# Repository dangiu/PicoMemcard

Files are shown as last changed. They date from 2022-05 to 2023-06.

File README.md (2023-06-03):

# PicoMemcard



PicoMemcard allows you to build your own supercharged PSX Memory Card that can be connected to your computer via USB in order to transfer saves directly to/from your PSX. You can use it to repurpose broken/counterfeit Memory Cards creating a better one using only a Raspberry Pi Pico.

## Features
* Able to faithfully simulate PSX Memory Card
* USB connection to import/export saves
* Allows to copy saves to/from any other memory card (using original PSX file manager)
* Allows to play burned CDs (thanks to [FreePSXBoot])
* Cheaper than an original memory card
* Can store hudreds of memory card images

## Bill of materials
* **Raspberry Pi Pico** (around $5)
* One of:
    * Custom [PicoMemcard PCB](#picomemcard-pcb)
    * Broken/Counterfeit/Original PSX Memory Card (counterfeit ones can be found on AliExpress for around $2-3)
    * PSX/PS2 Controller Cable
    * CAT5 network cable and a bit of creativity.

Basically anything that will allow you to interface with the memory card slot pins will do. If you have a broken contoller you can cut off the cable and use that since controllers and memory cards share the same bus. Of course, plugging your memory card into the controller slot will prevent you from using 2 controllers at the same time.

[This guy] assembled one using a 3d-printed plastic shell and simple CAT5 network cable. I belive this is the cheapest method anybody has come up with until now.

In total building a PicoMemcard wil cost you less than buying a used original Memory Card!

## Video
PicoMemcard (https://youtu.be/sPZsESXcDcc)

## PicoMemcard PCB

These are the custom PCBs designed and manufactured specifically for this application. They are not strictly required but make it much easier to build PicoMemcard since you don't need to cut up another memory card and all the soldering pads are easily accessible. All you need to do is to solder the Pico/RP2040-Zero on top of the PCB using a soldering iron.

The Raspberry Pi Pico or RP2040-Zero must sit flush on top of the PCB, fortunately both the Pico and RP2040-Zero provide castellated holes that are easy to solder directly to the PCB's pads. You can use some electrical tape to hold the board in place while you solder the first pins.

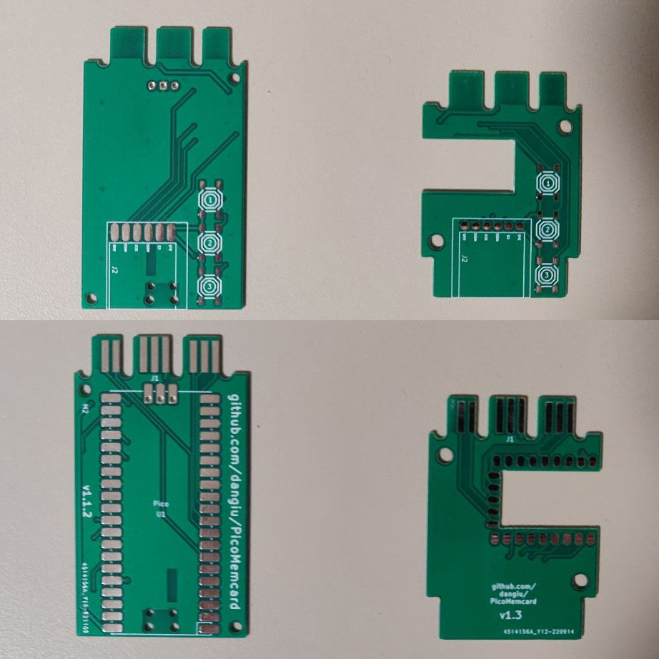
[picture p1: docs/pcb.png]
Custom PCBs


I've created a new version of the original PCBs the major difference are:
* The general size is smaller
* A new micro SD card module is supported. This module is smaller, easier to solder and should solve some of the power related issues that were previously present
* Is fitted for the installation of phisical switches used to switch memory card when PicoMemcard+ is used in systems that do not support switching via controller input (e.g. all PS2 models).

The KiCad and Gerber files are available in the repository. If you want to support the project you can request a PCB [from here]. 
Keep in mind that with the PS2 support release that will eventually happen the PCB may undergo some additional changes before its design is finalized.

## PicoMemcard using Memory Card
Raspberry Pi Pico and RP2040-Zero require different pin usage for full compatibility.

The wiring diagrams below show how to build PicoMemcard by wiring respectively a Pico and an RP2040-Zero to a counterfeit memory card. For the other cases (wiring directly to the PSX or using a controller cable) the pins on Pico and RP2040-Zero are the same, the pinout of the PSX/controller can be found on [psx-spx]. The images show the bottom side of the memory card with the cover removed.

Pico Wiring Diagram

RP2040-Zero Wiring Diagram

The dashed line on the PCB of the memory card is where you should cut a groove deep enough to disconnect the original circuitry from the traces. The yellow squares above the line indicate where you should scrape away the protective film in order to expose the copper traces and solder the wires onto them.

Finally the area at the bottom of the memory card is where you can cut a hole to feed the wires through connecting them to the Pico.
If you are using an RP2040-Zero you can also cut away part of the original Memory Card circuitry to fit it inside the original shell.

The connections in the PicoMemcard+ area are optional and only required if you want to build **PicoMemcard+** (using the optional MicroSD expansion board). Also remember to connect both ground and power to your SD card module (see [MicroSD Module](#microsd-module-for-picomemcard) section for more information).

## PicoMemcard vs PicoMemcard+
Since some features cannot be implmented when using only a Pico/RP2040-Zero but require additional hardware, I've decided to split the project in two versions:
* **PicoMemcard** simplest device to build, only requires a Raspberry Pi Pico / RP2040-Zero
* **PicoMemcard+** more complex and powerful device. Supports additional features such as multiple memory card images but requires additional hardware (namely the MicroSD SPI expansion board).

This approach was choosen because many people want a solution that is as cheap as possible and don't care about additional features. Conversely, others would like to have additional features even if it means spending a bit more money.

The current release of PicoMemcard+ additionally to all the features of PicoMemcard supports:
* Trasparent write-back: the sync operation performed to save new data no longer reults in the memory card appearing as if was briefly disconnected.
* Multiple memory card image switchable through controller input.

## MicroSD Module for PicoMemcard+
There are many variations of MicroSD expansion boards with different pinouts and interfaces. The only requirement for PicoMemcard+ is that the module must provide an SPI interface. SPI interfaces have at least the following pins:
* Chip Select (CS) (sometime also called Slave Select (SS)).
* Clock (SCK or CLK).
* Master Output Slave Input (MISO).
* Master Input Slave Output (MOSI).

In addition you will need to connect power and ground to your module, some modules are design to work with 5V others with 3.3V (or both), luckily for us both voltages are available on Pico and RP2040-Zero as shown in the schematic in the section [above](#picomemcard-using-memory-card). Some module provides additional pins that can be left disconnected.

The new versions of the PCB are designed to use small modules such as this one:

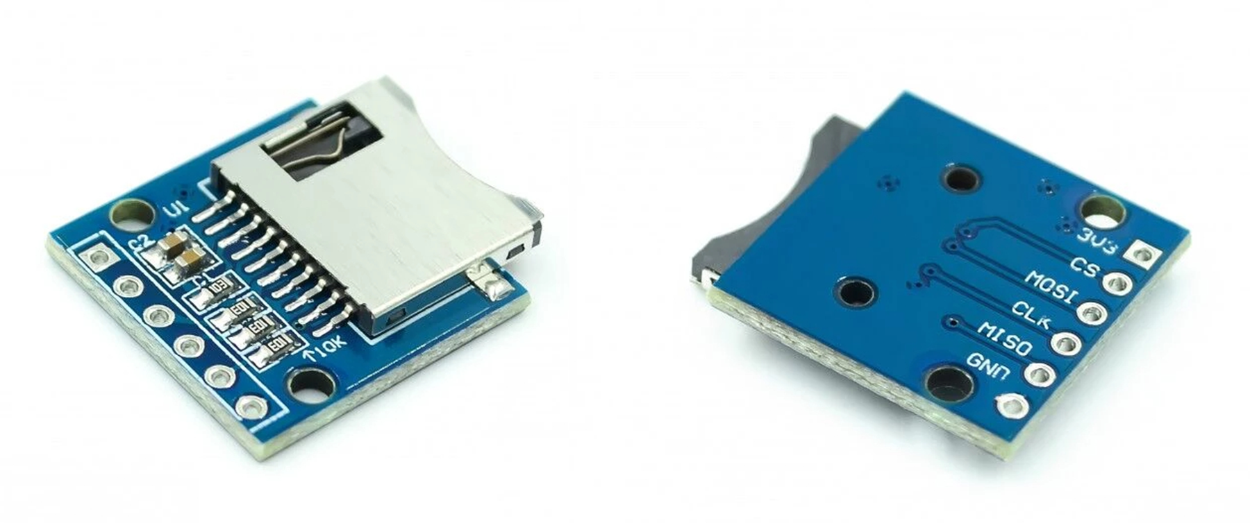
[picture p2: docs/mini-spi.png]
Smaller MicroSD SPI expansion board


This is mainly due to the following reasons:
* It comes withouth pre-soldered headers which makes it easier to solder onto the PicoMemcard PCB.
* Its smaller form factor allows for more flexibility.
* It should have less power issue than prevously used modules.

A good source for these modules is Aliexpress, in general you can search for `MicroSD SPI Expansion Board` and buy the cheapest one you find.

## Installation
1. Download the latest [release] for your board (Raspberry Pi Pico and RP2040-Zero require different binaries).
2. While pressing the 'BOOTSEL' or 'BOOT' button on your board, plug it into your computer. 
3. Drag and drop the PicoMemcard release onto your Raspberry Pi Pico.
4. PicoMemcard should appear on your PC as a USB drive.
5. Upload a memory card image to your PicoMemcard.

## Transfering Data
Memory card images must be exactly 128KB (131072 bytes) in size. PicoMemcard and PicoMemcard+ only support files with `.MCR` extensions. However, `.MCR` and `.MCD` extensions are interchangable and can be converted to one another simply via renaming.
For other file formats, try using [MemcardRex] for converting to the desired output.

* **PicoMemcard** only supports a single image which must be named exactly `MEMCARD.MCR`.
* **PicoMemcard+** supports hundreds of images. Each image must be named `N.MCR` where `N` is an integer number (e.g. `0.MCR`, `1.MCR`...). On boot your previously loaded image will be reloaded, unless it's a fresh card then `0.MCR` will be loaded.

Inside `docs/images` you can find two memory card images. One has a couple of saves on it so you can test if everything works correctly, the other is completely empty.

## Switching/Creating Images
On **PicoMemcard+** you can switch the active memory card image with the following inputs:
* `START + SELECT + DPAD UP` will switch to the next image (e.g from `1.MCR` to `2.MCR`).
* `START + SELECT + DPAD DOWN` will switch to the previous image (e.g from `1.MCR` to `0.MCR`).

Additionally you can create a new empty memory card image (and automatically switch to it) by pressing  `START + SELECT + TRIANGLE`.

**Attention**: this method only works on PSX if the controller used to provide the input is plugged in the same slot as PicoMemcard (exactly under it). Using a controller from a different slot will have no effect.

Additionally this method does not work on PS2 Memory Cards and Controllers are wired on a different bus.

## Syncing Changes
Generally speaking, new data written to PicoMemcard (e.g. when you save) is permanently stored only after a short period of time (due to hardware limitation). The on board LED indicates whether all changes have been stored or not, in particular:
* On Rapsbery Pi Pico the LED will be on when all changes have been saved, off otherwise.
* On RP2040-Zero the LED will be solid green when all changes have been saved, red otherwise.

Unlike **PicoMemcard+** that tries to write new changes as soon as possible, **PicoMemcard** will generally do it only after a period of inactivity (around 5 seconds). If you want to force **PicoMemcard** to immediately sync you can press `START + SELECT + TRIANGLE`.

**Attention**: after you save your game, make sure to wait for the LED to be solid green before turning off the console otherwise you might lose your more recent progress!

## 3D-Printed Case
I've finally designed a 3D-printable case for the different PicoMemcard PCBs. It helps inserting correctly the PCB and ensuring that the the connection to the PSX is optimal. The same result, albeit more janky, can be achieved using a folded sheet of paper as a spacer.

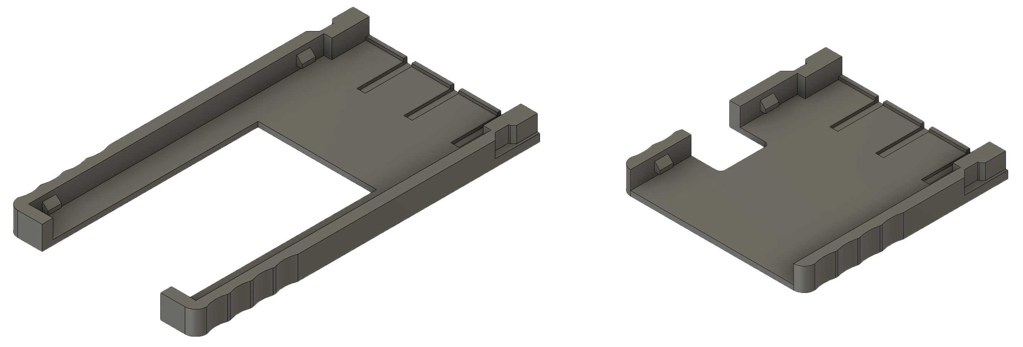
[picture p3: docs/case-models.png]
Model of 3D-printed case


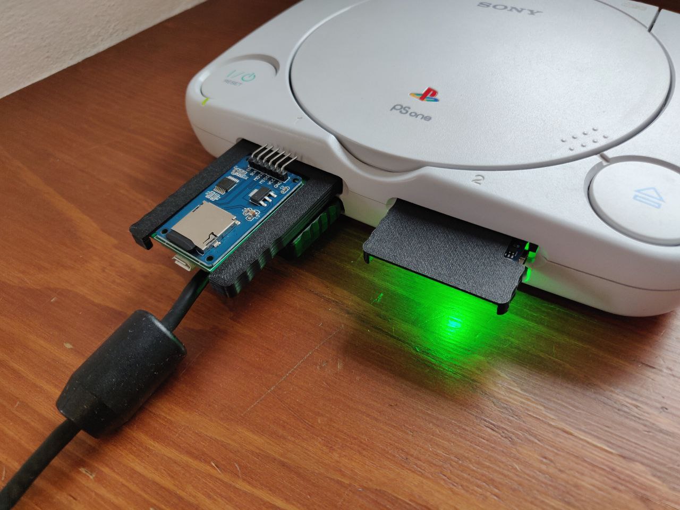
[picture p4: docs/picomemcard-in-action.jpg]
PicoMemcard in Action!


The cases are designed following a minimalistic approach, they consist of a single piece which holds tightly the PCB using very small clips without requiring any additional hardware. To assemble it, simply slide in the PCB from the back of the case (opposite to the side connecting to the PSX). Cases for the fullsize PCB are designed to support the MicroSD expansion module.

Here is the download for the STL files:
* [Design by DanGiu](https://www.thingiverse.com/thing:5488778)

If you don't like this case you can check out other designs many people have already created! I've not tested them personally but here they are:
* [Design by brik1111](https://www.thingiverse.com/thing:5453156)
* [Design by bbsan2k](https://www.thingiverse.com/thing:5460187)

## Troubleshooting and LED Indicator
Generally speaking the onboard LED will provide a pretty good indication regarding the status of PicoMemcard.

In particular, the RP2040-Zero has RGB LED that provides a more clear output. The Pico on the other hand as only a green LED and different blinking patterns indicate different statuses.

### PicoMemcard Status
| Status | Pico | RP2040-Zero
| --- | --- | --- |
| Failed to read memory card image | Slow blinking led  | Red blinking led
| Data not fully synced (do not turn off PSX)| Led off | Red led (or flashing red and green) |
| Data synced | Led on | Green solid led |

### PicoMemcard+ Status
| Status | Pico | RP2040-Zero
| --- | --- | --- |
| Failed to read SD card | Blinking led  | Red blinking led
| Data not fully synced (do not turn off PSX)| Led off | Red led (or flashing red and green) |
| Data synced | Led on | Green solid led |
| Memory Card image changed | Three fast blinks | Single blue blink |
| Memory Card image not changed (end of list) | Nine fast blinks | Single orange blink |
| New Memory Card image created | Multiple very fast blinks | Single light blue blink |

## General Warnings
I would recommend to never plug PicoMemcard both into the PC (via USB) and the PSX at the same time! Otherwise the 5V provided by USB would end up on the 3.3V rail of the PSX. I'm not really sure if this could cause actual damage but I would avoid risking it.

If you really need to have the Pico plugged into both the USB and PSX (e.g. for debugging purposes), disconnect the 3.3V line from the VBUS pin. In this way you can power on the Pico using a simple USB phone charger or by plugging it into your PC.

As a disclamer, I don't take any responsability for what will happen to your console when using PicoMemcard/PicoMemcard+.

## Project Updates
### 5 February 2023
Sorry everybody but I've been quite inactive on the project lately. Due to a change of job IRL I have less time to work for the moment.
Anyway, behind the scenes I've been trying to add support for PS2 memory card but I'm afraid that will require the addition of an extra hardware component unless I am able to develop an efficient cacheing mechanisms or something similar. Anyway I'll keep working on it when I have free time. I have in mind many improvement for the project and I think the future of it is going to be exciting.

Special thanks to everybody that supported it so far! You are all amazing.

## Design
For people interested in understanding how PicoMemcard works I provide a more extensive explanation in [this post] (although now somewhat outdated).

## Thanks To
* [psx-spx] and Martin "NO$PSX" Korth - PlayStation Specifications and documented Memory Card protocol and filesystem.
* [Andrew J. McCubbin] - Additional information about Memory Card and Controller communication with PSX.
* [littlefs] - Filesystem designed to work on NOR flash used by many microcontrollers, including the Raspberry Pi Pico.
* [ChaN FatFS] - FAT filesystem implementation for embedded devices.
* [Scoppy] - Use your Raspberry Pi Pico as an oscilloscope, very cheap and accurate. Without this I would have not been able to debug many issues.
* [PulseView] - Used to import, visualize and manipulate the data from Scoppy on a PC.

[FreePSXBoot]: https://github.com/brad-lin/FreePSXBoot
[psx-spx]: https://psx-spx.consoledev.net/pinouts/#controller-ports-and-memory-card-ports
[Andrew J. McCubbin]: http://www.emudocs.org/PlayStation/psxcont/
[littlefs]: https://github.com/littlefs-project/littlefs
[ChaN FatFS]: http://elm-chan.org/fsw/ff/00index_e.html
[Scoppy]: https://github.com/fhdm-dev/scoppy
[PulseView]: https://sigrok.org/wiki/PulseView
[release]: https://github.com/dangiu/PicoMemcard/releases/latest
[this post]: https://dangiu.github.io/2022/05/13/picomemcard.html
[from here]: https://forms.gle/f6XHtz6W5fn5qDZV7
[This guy]: https://github.com/MrSVCD/PicoPSX_3D
[MemcardRex]: https://github.com/ShendoXT/memcardrex

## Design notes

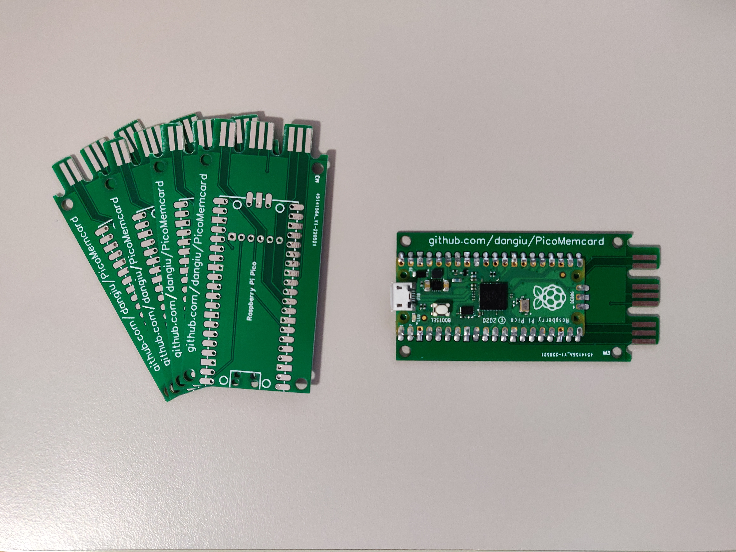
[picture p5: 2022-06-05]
docs/PCBs.jpg

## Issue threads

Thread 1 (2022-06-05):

VBUS connected to 3.3v

darrena092, 2022-06-05:
Hey,

Just setting this up, and I've noticed you say to connect VBUS on the pico to 3.3v on the PS2, which creates the danger that when plugging in the pico to usb, you'd be connecting that to 5v.

You can just connect the 3.3v memory card pin to 3.3v on the pico, and it'll power it just fine. That'll also allow you to safely have the board plugged into the PC for debugging at the same time.

darrena092, 2022-06-05:
(Also just to note I'm testing this with a Playstation 2 - I guess in theory at least it should recognise the PS1 memory card)

dangiu, 2022-06-05:
The problem with this approach is that the Pico can be powered on VSYS using only 3.3V (it expects a voltage already regulated). Some playstation models are documented to output more than 3.3 volts on that line (up to 5 or 7 if i remember correctly) so connecting it to VSYS would risk damaging the Pico.

darrena092, 2022-06-05:
Ah fair enough, mine didn't blow up anyways 🤣 - I'll measure the 3.3v line on the ps1 tomorrow.

dangiu, 2022-06-05:
Okk go for it! Same goes for my PSOne Model SCPH-102, measured some time ago but I guess you can never be too sure 😄

darrena092, 2022-06-08:
3.45v, a little on the high side. Will probably just leave the 3v3 line disconnected and power it from the PC while I'm working on it. I don't think an extra 150mv is going to cause all that big of a problem, but might be a good idea if there's a v2 PCB to include some voltage regulation, even just an SMT LM317.

dangiu, 2022-06-09:
Fortunately the Pico already regulates the power provided on VBUS (since USB normally uses 5 volts) down to 3.3V so there's no need for additional components 😀

Closed 2022-06-09.

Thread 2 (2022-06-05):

Not detected by Playstation 2 - SCPH-39003

darrena092, 2022-06-05:
Hi,

Tested this today with my original fat playstation 1, worked perfectly (using the breakout board I talked about on the Reddit thread that I'd made a while back).

When trying it with my Playstation 2 (SCPH-39003), it wasn't detected at all. Not sure what the issue there is, but I'll try to debug it if I get time. I understand the primary purpose of this project is for use on the Playstation 1, but it'd be nice if it also worked in backwards compatibility mode on the PS2 also.

dangiu, 2022-06-05:
Ok! Glad to hear it works on FAT PS1, could you provide the exact model? I'm just curious to know. I'm not sure on the protocol the PS2 uses to communicate with memory card, maybe the interaction is slightly different and messes up the PIO state machines.
If you have an oscilloscope it would simplify the debugging process a ton! I used another Raspberry Pi Pico together with [Scoppy](https://github.com/fhdm-dev/scoppy). Thanks for your contribution!

darrena092, 2022-06-05:
The PS1 is a SCPH-9002 btw

darrena092, 2022-06-08:
This might be simpler than what you think.

Getting the following over UART:
```
SYNC    OK

Unknown MC CMD: 11

Unknown MC CMD: f3
WRITE  003f
```

Looks like there are just a few unimplemented commands that the PS2 sends, which the PS1 does not. I'll work on figuring out what they are and get them handled.

darrena092, 2022-06-08:
Nah scratch that, something weird going on. Going to hook up the logic analyser.

darrena092, 2022-06-08:
I have a theory, those 0x11 and 0xF3 commands aren't actually real. They seem to be generated when the PS2 does this:

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

I unfortunately don't have a real ps1 memory card to test with at the minute, but I'd imagine this must be part of some sort of mechanism to figure out whether or not the memory card is a PS2 or PS1 one.

The issue might be ACKing that. Hard to say without having a real one to test with at the minute, but I'd say we probably only want to ACK on /SEL with 8 clock pulses. I'll see if I can modify it to do that and report back.

uyjulian, 2022-07-08:
For reference, if the card inserted was no card or PS2 card before, it will attempt to probe in this order: PS2, PS1, PocketStation

Otherwise, it will probe in this order: PS1, PS2, PocketStation

Reference: https://github.com/ps2dev/ps2sdk/blob/f5401e0c95e85900464c550060da4c9b9ee6b67b/iop/memorycard/mcman/src/main.c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

darrena092, 2022-07-10:
Fixed in #10 (not yet merged) - though the fix is specific to the SD card version of the project due to problems with littlefs hard faulting the CPU with the new sector at a time sync process.

dangiu, 2022-08-02:
Fixed in new release

Closed 2022-08-02.

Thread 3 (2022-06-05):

With RP2040 zero，ps1 not detect

sceic, 2022-06-05:
With RP2040 zero, the .mcr file can be recognized through usb after writing the program. However, it cannot be detected by ps1 9002. It has been checked  3.3v power supply and the data line connection are not abnormal.

sceic, 2022-06-05:
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

darrena092, 2022-06-05:
How are you testing whether or not it detects it? Did you program it with an image containing saves and they don't show up in the bios?

Also, have you checked continuity between the edge connector on the memory card and the copper pads on the rp2040 zero board?

sceic, 2022-06-06:
How are you testing whether or not it detects it? Did you program it with an image containing saves and they don't show up in the bios?

A: Tested through the ps1 bios - memory card management interface, the slot 2 card cannot be copied to the Pico memorycard（slot 1）.

Also, have you checked continuity between the edge connector on the memory card and the copper pads on the rp2040 zero board?

Edit: Did you also cut the traces fully? It's hard to see from the photo. That could cause it to have a bad time too.

darrena092, 2022-06-06:
That's really interesting, so it works in a game, but not in the bios. You can't see your save icons in the memory card browser? In your first comment you said it's a SCPH-9002?

dangiu, 2022-06-06:
Very interesting indeed. SCPH-9002 is a PAL model running bios version 4.1 I believe. It would be interesting to test if other models with the same firmware version behave equally.
I have a couple of questions:
1. Do you have an oscilloscope? Could you capture the data being exchanged between PicoMemcard and PSX
2. In what game can you use it correcly to save/load? Could you try a couple different games?

sceic, 2022-06-07:
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

I have an oscilloscope Rigol DS1102Z-E (100MHz bandwidth and 1GSa/s) but need guidance on how to test data exchange as I just bought it.

The game is FinalFantasy 8, other games have not been tested, I will try other games later, such as Tomb Raider 2.

sceic, 2022-06-07:
> That's really interesting, so it works in a game, but not in the bios. You can't see your save icons in the memory card browser? In your first comment you said it's a SCPH-9002?

In bio.  memory card browser no icons.  and can't copy saves betwin slot1&2.

Yes,my PS1 is SCPH-9002.

darrena092, 2022-06-07:
Odd, I'm using the same console, SCPH-9002 and saves show up fine in the bios.

dangiu, 2022-06-07:
>

I'm not familiar with that model of oscilloscope but I can give you some general advices:
- double all of the connection on the memory card side and hook them up to the oscilloscope
- look for something like "record fixed amount of samples"
- plug in your PicoMemcard and trigger the recording process measuring the communication
- desolder the RP2040 zero leads but leave the connection to the oscilloscope
- now plug in a working memory card and trigger again the sampling process
If you could share both results (RP2040 zero communication and working memory card communication) it would be really helpful to debug your issue.

dangiu, 2022-06-07:
Ok keep me updated 👍

sceic, 2022-06-09:
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

I moved the RP2020 zero into the same memory card case as the author, and the integrated size is very good. I have a feeling that the original problem might be related to the MCR file that was originally generated, but it's working fine now.

dangiu, 2022-06-09:
>

Yes it's normal. Because firmware for these chips are statically allocated, meaning that they get always loaded in the exact same address. In this case the program does not overwrite the part of flash memory containing the filesystem with the MEMCARD.MCR file.
If you want to completely wipe the flash memory the Raspberry Foundation provides a special uf2 file called something like flash_nuke. It's near the bottom of this page: https://www.raspberrypi.com/documentation/microcontrollers/raspberry-pi-pico.html

Anyway the initial MEMCARD.MCR file shown on the first boot is actually just a placeholder (if you look it's actually 0 byte in size). That's why no savefile was popping up in your bios. In the repo (under "docs/images") I provided 2 memory card images you can use to test.

dangiu, 2022-06-09:
> very good. I have a feeling that the original problem might be related to the MCR file that was originally generated, but it's working fine

That tight integration looks great dude!
I will now close the issue since the problem has been solved.

Closed 2022-06-09.

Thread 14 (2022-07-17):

Randomly disconnecting

Androxilogin, 2022-07-17:
I noticed this happening during the Saga Frontier load menu. It will read the data then disappear. If you choose your save quickly you can get it to load. I've tried it on two Phat models with the same result. https://imgur.com/a/tmWFf1v

dangiu, 2022-07-18:
I'll look into it, thanks for reporting!

Androxilogin, 2022-07-19:
Sure! Just happened to be the first game I tried it with. Haven't tried saving with that particular game since I was wondering if it was maybe my wiring and moved on to other titles to check.

dangiu, 2022-07-20:
Is the game Sega Frontier SCUS-94230 (NTSC version)? I'm a bit busy in these days but I'll definetly check it out... I have already a couple of ideas on what might be going on.

Androxilogin, 2022-07-23:
That's the one. I also have been taking inventory of a few other things that I noticed. I'm not sure if you have a regular memory card or not to go against but what I've noticed so far:

*If you plug the memory card in while the console is powered on it will reboot.
- You're probably aware of this one but it is inconvenient. Perhaps nothing can even be done about it.

*While in the memory card menu in the bios it acts abnormally.
- With a regular memory card, once you copy some data to it it will just stay on the screen. I was reading your background on [how this project came to be](https://dangiu.github.io/2022/05/13/picomemcard.html) and noticed that the way it's writing to the ram is probably the cause. But anyway, figure it should still be mentioned. Copying data to it causes a few seconds pause and then everything is loaded in again. Which brings me on to my last report.

When you're in the memory card bios screen with a typical memory card and you accidently delete some data, there is a data recovery that can be done to salvage that save that was just deleted by pressing L1, L2, R1, R2 all at once a few times and it will load in each save one by one with the save showing back up in the list. With the Pico, this is no longer an option.

And no problem. It's your project, I just think it's cool. As a kid I was always fascinated by the look and thought it was crazy it was capable of holding data. Especially animated tiles that held data! That was something else back in the day.

I've also tested this with the MemCarduino project and it works as expected. Although unnecessary as it is. One last thing I was wondering about was why it had to use MEMCARD.MCR specifically as the name. Guessing it calls for that name specifically while searching for data? Is it something you plan on changing in the future?

dangiu, 2022-07-24:
Lots of things worth discussing.
Regarding the abnormality in the BIOS is exactly what you mentioned. The syncing process between ram and flash causes the problem. Unfortunately that cannot be avoided when using Pico internal storage. A mitigation I'm planning to introduce is lengthen the delay between sync (e.g. to 10 sec) and add an option to sync "manually" using a specific controller input (also blinking the led while the sync is in progress).

Regarding the data recovery I didn't know that there was such function! What kind of PSX model and BIOS version do you have? I need to check the code on how block delation is processed by PicoMemcard, it shouldn't be too hard to fix.

Regarding the name, yes it is checked in the code. I placed it initially and never improved on it... Can easily be changed :)

Androxilogin, 2022-07-26:
I actually have a SCPH-1001, a SCPH-7501 and a SCPH-101 I've been testing with. As for the bios versions, I'm not exactly sure. I've recently been trying to get things cleaned up a bit for new and incoming projects so ended up throwing them in the closet. I have another SCPH-1001 coming in a couple days to restore so I'll be digging out some old parts consoles, I'm sure. So far they've all behaved the same way consistent with all I've tested but I'll keep you posted if I stumble onto anything interesting or odd.

Androxilogin, 2022-07-29:
Update: I am not having problems with Saga Frontier anymore. It must have been the way the case I made previously seated the pins. I've also tested this on two different PS2 models and neither would work with them.
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

dangiu, 2022-08-02:
Awesome job on the PCB case, is the design publicly available?
Everything mentioned in this issue should be fixed in the new release.

Androxilogin, 2022-08-03:
You've sure been busy with this. I have not released the design publicly. The custom board was fitted very specifically and I may change the design again slightly. The MicroSD is a bit overkill for me personally but the 2040-Zero would allow for a smaller footprint. Curious to know, before adding the flash file, the device actually has somewhere around 200mb? Is this impossible to add a push button switch to the pi and enable different cards via flash if it were written differently? Also, do you plan on adding an LCD in the future? I'm not even sure if that's possible with these modules but it would be cool to see!

dangiu, 2022-08-03:
The Pico only has about 2MB of flash, the problem about supporting multiple cards (beside the limited space which would allow only a few) is having an intuitive way of transfering them. The solution right now is to use USB mode and an in-RAM disk as a sort of bridge between OS and pico's flash memory. Theoretically, using a button to select where the RAM disk maps to flash should be possible.
Regarding the LCD somebody already introduced support for a small OLED monitor during development, however this feature is not yet ready for release as introducing it would prevent users without one from being able to use PicoMemcard.

Androxilogin, 2022-08-04:
The drag and drop convenience is definitely a winner for me. As for the OLED, that's awesome! I don't know why I said LCD. This project seems it might surpass the MemCard Pro very quickly. Someone also shared this board idea from a similar project they found on the psx.dev discord.
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

Closed 2022-08-02.

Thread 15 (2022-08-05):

PicoMemcard+ will not record the chosen slot

Raphfriend, 2022-08-05:
For example, if I select file 2, when I remove and re-insert Picomemcard+, it will return to the first file. Is this behavior as expected or have I done something wrong?

dangiu, 2022-08-08:
This is the expected behavior for the current implementation. File 0 is always the one chosen on startup.
I will label this as a new feature.

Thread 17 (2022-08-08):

Where to find SD Card Modules

Androxilogin, 2022-08-08:
I meant to fit some cases for the variations of files offered here but I'm running into some problems. I bought two different kinds of boards and they each have their own set of issues. The **[Adafruit module](https://www.adafruit.com/?q=Adafruit+Micro+SD+SPI+or+SDIO+Card+Breakout+Board+-+3V&sort=BestMatch)** is well built but also a bit thick & pricey. While fitting with the basic Pico Pi (longer version) it seems like it may be impossible to fit in the case comfortably. The board itself is about 1.76mm without the card slot. About 3.70mm (height wise) altogether and 23mm in length. The other board is around 3.50mm thick but with a little over a whopping 42mm in length.

What I'm looking for is what board you would generally recommend so I that if I were to share a case here that everyone would have a perfect fit. I'm also a bit confused with the **[wiring of the board I got](https://imgur.com/BZVWM92)** if this is what were to be recommended. Or at least for testing.

I have a few of the 2040-Zeros on the way but it seems they were outsourced from China so it's going to take a little bit longer. I plan on making a case for both models, small and large with and without the SD module. Looking forward to shortening up the case to at least the regular size of an official memory card when my Zeros get here.

Raphfriend, 2022-08-09:
You can wire directly. I din't find any documentation, so i just did the test.
That's mine:
<p align="center">
  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
 <br>
  <b></b><br>
<br>

JAOT, 2022-08-09:
Heh.
I don't really care for pretty devices, as long as they work. I converted mine to a Pico

Memcard+ with an SD Connector I had that wasn't going to be used.
Had to connect the 3.3v and ground pins, though, as without them, the computer saw a drive but was unable to mount it.
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

Here's how it looks:
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

It's picky regarding the memory cards used, though, but I'm sure that is because of a mix of the adapters used and cards.
I'm currently using a 128MB card, and for the PSX that is unlimited saves! :D

dangiu, 2022-08-10:
For SD card modules I would reccomend looking up "microSD SPI" on a website like Aliexpress.
Regarding the connection of your module you can look it up on https://en.wikipedia.org/wiki/SD_card#Transfer_modes
In particular the Pico supports the card in SPI bus mode, so those are the pinout that you should use (the table gives you the conversion for your pinout to the one used by the wiring diagram).

@Raphfriend never seen an SD card wired directly, pretty cool!

Androxilogin, 2022-08-10:
From that wiki I found:

MOSI:D1
SCK:CLK
MISO:D0

So I'm guessing SS is CS?
Also, 3v (Out) and GND should be connected? I've been trying with a different SPI that I got off of Aliexpress for arduino **[similar to this](https://imgur.com/fuGddas)**. I attached the VCC to 3v3 out and GND to GND, SS to CS but seems it's not working. Tried two different cards. Should it be formatted to FAT32? I've tried FAT & FAT32 but it hasn't shown up. Just an unhighlighted drive. Ejecting/inserting shows no difference. I've used these modules in other projects in the past and have came across a few that were defective. I have yet to test the one I've pictured above. Figured I'd ask first before I burnt something up.

dangiu, 2022-08-11:
Yes SS is CS and both 3v3 and GND must be connected. Your connection seems to be correct! Yes FAT32 file system should be used.
The picture you have linked is the exact same adapter that I'm using.
Let me know how it goes :)

Androxilogin, 2022-08-17:
That might explain it. I probably waited a total of around 10 seconds at most each try. I've since disconnected the wires for the current Pico I've been working with. Been waiting on my mini Pis to do some more testing. Figured they'd have been here a lot sooner. Ah, well. Hopefully I'll be back at it by tomorrow.

Androxilogin, 2022-08-18:
I hate to double post so here is my previous entry as well as my update:
*That might explain it. I probably waited a total of around 10 seconds at most each try. I've since disconnected the wires for the current Pico I've been working with. Been waiting on my mini Pis to do some more testing. Figured they'd have been here a lot sooner. Ah, well. Hopefully I'll be back at it by tomorrow.*

So yesterday I came up with a case and put it all together but I'm still having issues. I've tried three different SD cards formatted to FAT32, waited well over 30 seconds, I don't know what the deal is. When plugged into the console it blinks red. Supposing this is an indicator for it not being detected. Attached to the PC, it doesn't pass it through, still just a grey transparent drive showing up. I was too tired to comment here last night, here is what I came up with for the Adafruit and Pi-Zero board combo.

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

dangiu, 2022-08-18:
Very cool case design, one suggestion I have for troubleshooting: have you tried setting up the sd card (moving a 0.MCR memory card image) using a normal sd card adapter and then plugging it into the RP2040 and psx?
I'll try to recreate the same situation as soon as I have a bit of time. It might be possible that a bug of some sort slipped into the release and I haven't tested it properly.
If anybody else managed to get PicoMemcard+ working on an RP2040-Zero please post a comment.

Androxilogin, 2022-08-18:
Thanks- I forgot to mention that I had to snap the reset button off my board to have it fit correctly. I had a feeling it might be a problem as soon as I hit print but I let it go just to see. I'm fine with that but I should probably correct it.

Yes, I have tried that. And I reformatted the card(s) and made it the only data that was on them just to be sure. I'll post a diagram of my pinout based on what you have here hopefully later today just to be sure it's 100% correctly wired up. Has anyone else here used the Adafruit board? I'd assume it should be a great candidate.

qxc86, 2022-08-20:
> If anybody else managed to get PicoMemcard+ working on an RP2040-Zero please post a comment.

Tested just now on the precompiled release image with no issues. I'm also using an adafruit breakout board like yours. Wired as follows:

```
MOSI > SI
MISO > SO
SCK > CLK
SS > CS
 ```
Which should be the same way as above. The only oddity I ran into was, I had some trouble until I wired both the PS1 power line and the breakout card via the 3.3V line on the RP2040 Zero, contrary to the README picture. Using an off brand 32GB card.

Androxilogin, 2022-08-20:
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

Holy crap, it freakin' works. My MOSI was connected to D1. Just grabbed the soldering iron real quick and moved the wire over to SI and Bam. Worked right away. Thank you soo much! Now I can actually get to messing around with this thing. I did have my 3.3v wire split off as you do at first but later switched it to the 5v. Seems to work fine here and the cards seem to switch super fast!

qxc86, 2022-08-20:
I would be a little worried about having the SD module wired to the 5V line if you ever connect via USB, but that's how mine was for a while and I didn't fry my card. Presumably the 5V pad is outputting 5V when USB is connected, but I haven't actually taken a multimeter to it. I could have also had a bad connection before I moved them, it's difficult to get two wires on the same pad lol. YMMV.

Where did you get those memory port pads? The whole setup looks super good!

Androxilogin, 2022-08-20:
I was worried about that initially. My 5v line is connected to the memory card port connector to avoid any overdraw. While plugged in, the USB port is inaccessible to avoid any accidents. The boards were drawn up in KiCad. I had to wait around a month to get my initial model design finished since I was building around the board. A bunch of prototypes later I have two variations done. One for the original RPI2040 without a Micro SD and now this one that I can match up with different modules I test. Now I'm going to go off into a ramble outside of anything you asked, but it has to do with the topic of this title.

* **SD Slot:** *
Most common seem to be the cheaper AliExpress models so I should order some of those to get fitted. I definitely want to go for the shorter boards to make it seem more authentic. 24mm X 42mm is what the page says but that could differ from the actual product. I'm especially confused seeing the size difference of the two pictured claiming to be the same size:

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

* **Case** *
I did mess around with the aesthetic markings of an original memory card such as the space for the labels and the triangle at the top but it came out as bad as I thought it would. It could be accomplished if printed differently which would take away a lot of the strength and open up the possibility of pieces snapping off inside console ports so I discarded that idea.

qxc86, 2022-08-21:
Haha yeah the measurements on the second one look a lil suspect.

Hoping you're planning to post the board and 3d printing info publicly at some point. Would be very interested in making one, albeit I'd probably want to sub in the QTPY 2040 instead of the Zero. The Zero is the largest "very small" 2040 board on the market so if it fits, anything else should.

How is the durability of the internal bracing? It feels like USB-C takes a lot of force to connect and disconnect, at least relative to how big these things are.

Androxilogin, 2022-08-21:
Being that the port connector boards are extremely inherent to the design I'm not sure how I want to go about it yet. I figure I'll cross that bridge when I come to it. I'm not too keen on moving into the whole USB Type-C aspect of it. I stubbornly still feel that the previously released generation is sufficient being that most of my devices use them but I did buy some cheap converters to quell my ignorance of their usefulness.

If there is a file released here for the QTPY 2040, I'll most likely make a design for that as well. The durability is excellent. 1mm walls are surprisingly efficient with small components. There's also room to spare in making the walls larger but I don't see any need to. I did mention previously in this thread about some really bad filament I was using to prototype that was hilariously terrible. I discarded it for accuracy but it was an interesting experiment. Very light pressure and I was snapping pieces off everywhere. It was a spool that came with my printer which I completely forgot about so it was worth a test. Everything came out pee colored and delicate as a waffle chip.

The USB-C connector actually sits about a mm behind a wall so part of the case can slide forward past it as it's being locked into place. The zero dips into the bottom .5mm to make room for the underside components and rests on top of four 1mm high pillars. Then walls surround three sides for most of the length to give it a really robust positioning. I went back and forth on a forth wall coming to the conclusion that it didn't need it and could potentially over complicate things. The inner walls came up from the bottom of the board with enough spacing as not to pinch the wires even if they happen to overlap. At some points it was a bit rough fitting everything into such a small height.

I've also ordered some of those shorter SD modules just after my last comment here. I have one of the longer version I was using for other projects, just not sure if I want to build something around it due to the size. So hopefully the size in the picture above is a lie for these new ones. My micrometer says this other board is correct.

Closed 2022-08-31.

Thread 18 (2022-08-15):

something wrong with current PicoMemcard+.uf2 file?

copywizard, 2022-08-15:
Hello after some testing i first thought my pico was broken or my soldering skills where to blame but somehow if i download the current PicoMemcard+.UF2 file and try to flash it to my PICO it closes after copy and does not pop up the PICO MC usb storage.
But when i use the PicoMemcard.UF2 file it works perfectly!

so my conclusion is there is something wrong with the +.UF2 file

qxc86, 2022-08-16:
Can confirm this behavior, my assumption is that reading and writing was intended to be done with the microSD card rather than the USB port with pmc+ . Unsure if this is a correct assumption or not.

copywizard, 2022-08-16:
@qxc86 do you mean if i flash the + image i just have to wait 30 sec+ for the usb storage to show up?

dangiu, 2022-08-16:
Have you verified to have a working SD card (and SD card module) connected to your pico and formatted using FAT32 filesystem? Otherwise it will not show up.
When using PicoMemcard+ the Pico simply acts as a passthrough for the SD card but reading and writing is somewhat slow.

copywizard, 2022-08-16:
ok thats something i did not know i had hoped it would work without the sd card then i was just mis informed this can be closed.

p.s. i will get a sd card SPI module asap

Raphfriend, 2022-08-16:
I recommend that you use another SD reader because the RP2040 is quite slow in terms of transfer rate. As @dangiu  mentioned, it's probably expected behavior.

copywizard, 2022-08-16:
Sorry I did not mention this but I,am using a full size RPI pico and a daughter bord from dangiu.

I soldered on the RPI pico and it works fine used it all day with the normal version of picomemcard but when I put on the + version it just does not work.

But I have ordered some micro SD card spi modules and it seems the daughter bord from dangiu already have the proper pinout for it on the back so when it comes in I will solder that on and hope it will work with the + versions then?

Raphfriend, 2022-08-16:
@copywizard If you look at [this topic](https://github.com/dangiu/PicoMemcard/issues/17#issuecomment-1209271257), you'll notice that I'm using direct wiring on an SD to microSD adaptor, and it's working fine. However, when I try to read on my PC, it is quite slow, either in terms of being recognized by Windows or transfer rate (about 88Kb/s).

I think any microSD addon should work.

copywizard, 2022-08-16:
@Raphfriend thank you I have seen this topic before but I hope to do a more clean job right now the dangiu daughter bord and pico work fine I will post the final results when I get the SD card reader in and working hopefully the write speeds will be a bit better then mentioned?

dangiu, 2022-08-16:
> @Raphfriend thank you I have seen this topic before but I hope to do a more clean job right now the dangiu daughter bord and pico work fine I will post the final results when I get the SD card reader in and working hopefully the write speeds will be a bit better then mentioned?

Yes, if the pinout of the SD expansion board is the same it will work right away... I've based my design on modules commonly found on Aliexpress (e.g. https://it.aliexpress.com/item/32877331401.html)

Raphfriend, 2022-08-16:
We don't need the regulator because the pico (even ZERO) already has 3V3, so what's the intent of the second IC?

copywizard, 2022-08-16:
@dangiu I have ordered that precise one and the smaller version here that somehow has another pinout.

https://a.aliexpress.com/_v01seV

qxc86, 2022-08-16:
> @qxc86 do you mean if i flash the + image i just have to wait 30 sec+ for the usb storage to show up?
>
> Because if i do so i see a new usb device pop up but it is unusable/inaccessible

Less than 30 seconds, it's not quite as fast as the onboard PMC flash as far as showing up. Testing a few times just now it took 8-10 seconds. It did take around 30 seconds after clicking the disk icon in linux for it to finally load the contents however, long enough to think that it was not going to work. As mentioned, using the USB to manage files on the microSD card is very sub optimal. You're much better off just attaching the SD card directly to the computer via adapter.

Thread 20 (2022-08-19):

LED Not working on RP2040-Zero when building from source

qxc86, 2022-08-19:
I can not get the LED to function as expected on the Waveshare RP2040 Zero when I build the code myself. I currently have the board wired up only to the PS1 pins, no SD card pins wired. The expected behavior is a flashing red LED when connected to the PS1 indicating it can't read the SD card image. I've confirmed that the current release image available does work as intended, and to my knowledge there are no changes between that and the current release branch.

I'm building from the `smc+/release` branch, with the only change being the following:

```
$ git diff
diff --git a/inc/config.h b/inc/config.h
index 218120d..f2780f0 100644
--- a/inc/config.h
+++ b/inc/config.h
@@ -10,8 +10,8 @@
 #define MC_RECONNECT_TIME      1000                            // time (in ms) the memory card stays disconnected when simulating reconnection

 /* Board targeted by build */
-#define PICO
-//#define RP2040ZERO
+//#define PICO
+#define RP2040ZERO

 /* PSX Interface Pinout */
 #ifdef PICO
```
Which should set the target board appropriately. My build process is:

```
export PICO_SDK_PATH=~/pico/pico-sdk/
mkdir build && cd build
cmake ..
cmake --build . --target all -j 10
```
Building on Ubuntu. No warnings except for a couple at the very end, all part of the SD submodule.

dangiu, 2022-08-20:
I bet the problem is that compilation requires a fix for pico-sdk (regarding multicore lockout functionality). I only mentioned in the commit messages but it got buried in the history.
Here is the relevant pull request:
https://github.com/raspberrypi/pico-sdk/pull/936

qxc86, 2022-08-20:
Ah yes, I remember reading about that but had assumed it was merged into the main branch already.

I changed my pico-sdk folder over to `development` branch, confirmed that the commit in question was present in git log and confirmed `PICO_SDK_PATH` was pointed to that folder, but my built binary still did not work. Went back and forth between that and the precompiled to make sure I didn't break a wire. I'm assuming this is a failure in me knowing how to correctly pull in those added changes to the SDK now.

dangiu, 2022-08-22:
Is there any possible way for you to debug the program and see where it gets stuck? That would really be helpful

qxc86, 2022-08-23:
Is it possible to do that without using the debug pins on the RP2040? The QTPY RP2040 and RP2040 Zero don't have debug pads on the board. I tried soldering wires directly to the pins coming off of the RP2040 but that's beyond my capabilities. My basic understanding would assume since USB is used for presenting as a USB device for the PC, it can't be used for debug?

dangiu, 2022-08-25:
Exactly, unless some heavy code modifications are present but that would defeat the purpose of debugging the current code :/

dangiu, 2022-08-31:
Are you still having the same problem? Can you try with a different machine?

qxc86, 2022-09-06:
Just got around to trying the new version this weekend. Same issue as before, mostly.

To try and isolate the issue I got a fresh image of raspberry pi os and loaded it onto my pi 400 so I could start from scratch, including the env.

```sudo apt install cmake gcc-arm-none-eabi libnewlib-arm-none-eabi libstdc++-arm-none-eabi-newlib
cd Documents/
git clone https://github.com/dangiu/PicoMemcard.git
git clone https://github.com/raspberrypi/pico-sdk.git
cd pico-sdk/
git submodule update --init
git checkout develop
cd ../PicoMemcard/
git checkout pmc+/release
<edit inc/config.h to comment out #define PICO and uncomment #define RP2040ZERO >
git clone https://github.com/carlk3/no-OS-FatFS-SD-SPI-RPi-Pico.git
mkdir build && cd build
export PICO_SDK_PATH=/home/pi/Documents/pico-sdk/
cmake .. && cmake --build . --target all -j 5```

I also tried with `pico-sdk` checked out to `fe7849d` and the fatFS module to `4f09f02` with no change. Pardon any typos, I had to copy this all over by hand because I didn't want to log in via the pi. I did just go back and retype them into the pi with the same results however.

Why didn't I use submodule update for the PicoMemcard repo? Because it fails with access permissions. :shrug:

Hopefully something in there is obviously wrong, or you're able to replicate on your end.

realJoshByrnes, 2023-03-19:
https://github.com/dangiu/PicoMemcard/pull/44 should fix your access permission issue. Can you try pmc+/development branch?

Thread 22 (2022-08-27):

Onboard Hardware Buttons

Androxilogin, 2022-08-27:
In reference to the limitations of the PS2 controllers being on a different bus, I was wondering if it would be possible to use the onboard Boot & Reset buttons optionally to switch cards.

Also, on the idea of implementing PS2 Memory Card emulation in the future I was wondering if you also had plans to add the same abilities as **[MC2SIO](https://heldergametech.com/shop/ps2/mc2sio-microsd-iso-loader/)** to load ISOs through HDL. I know it's a pile of questions to throw out there but this would be revolutionary. Say- if the Boot and Reset to switch cards back and forth is possible, something like hold Boot for five seconds to switch between PS1 and PS2 card emulation modes verified by blinks or colors.  Hold reset for five seconds to enter PS2 ISO emulation mode. That would be soo handy with McBoot.

Perhaps tap the Boot button twice to create a new PS1 card, Reset twice to create a new PS2 memory card. Both automatically switching to the new card and verified with a blinks; color hold while creating.

Again, just throwing out ideas I've been curious about while ignorant to the limitations. Not saying, "oh, you should totally do this!" Also wanted to **[share this crumby video](https://www.youtube.com/watch?v=8dUKlE79xmk)** I made the other day showing off that card I put together with the Adafruit module as well as the button functions (before the last update).

qxc86, 2022-08-27:
I don't think the actual GPIO calls are in the code but that did get implemented as part of [this yet to be released product](https://twitter.com/angryhelder/status/1554542618939359232) to my knowledge. It's something I also want to put in whenever I'm done porting the code to other RP2040 boards.

My limited, probably incorrect assumption about how MC2SIO/MX4ISO works is that it's communicating _directly_ to the PS2 by using a driver they wrote to interface with the SD card itself. The boards made for this don't have any ICs on them, [they're mostly passive adapters](https://www.psx-place.com/threads/mx4sio-sio2sd-sd-card-adapter-and-sd-driver-for-the-ps2-sio2-interface.29210/). I don't know if you could pass that through the RP2040 at all, let alone without additional latency issues or what not.

Looking forward for public files for those cards in the video, by the way! I wanna build a couple up that aren't a bunch of parts hanging out of a torn up third party card lol

Androxilogin, 2022-08-28:
I'm pretty much assuming that some of these questions I had are not possible but figured I'd throw it out there for those who might know.

As for my case files, I'm not real sure if there will be a public release or not. There are many reasons for this, including the fact that I've built these around custom PCBs I designed for them to fit exclusively. This was unintentional but seems I won't be turning back now on these current designs. I plan on reworking these boards based on the same sizes but with through-hole vias in the future to make soldering cleaner and easier. The thickness and width are not sized as the original and with such connections, small imperfections as low as 0.1 could cause it not to function whatsoever. I figure I'll decide once I get to the point of satisfaction with all variations I've been working on, where I want to go from there. While I do appreciate contributing to the community, I've had designs in the past taken, branded and mass produced for profit without my knowledge or consent so I'm very cautious of what I distribute. I'll work in many aspects of providing diagrams, bug reports and suggestions, along with getting the word out to build interest. If I knew more about the coding besides recognizing only what has already been written I'd assist with that. Outside of that, I prefer to keep my models independent.

I do **[offer a number](https://www.thingiverse.com/androxilogin/designs)** of simpler designs I've created that are useful for other consoles. **dangui** has made his own single boards and has planned a case for it in the future as well. I'd have built a case around their PCB to publically distribute if I had one.

dangiu, 2022-08-31:
@Androxilogin can you open a different single issue regarding only onboard hardware button? I'll label that as a feature and close this one since most of it's content is off topic, that way I can keep things more clean and organized following a logical thread.
Regarding your questions I will answer more in detail in the dedicated issue... The TLDR is that using the Boot switch has very heavy limitations and is not possible for most of the stuff I would like to do, using the Reset button is straight impossible since is tied directly to the pin that resets the MCU.

Androxilogin, 2022-08-31:
It's fine, I'll just leave it in your hands and see whatever develops.

Closed 2022-08-31.

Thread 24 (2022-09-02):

Image Swtitching Hardware Button

dangiu, 2022-09-02:
As mentioned by @Androxilogin since on PS2 memory card and controller bus are separate PicoMemcard cannot detect controller input therefore memory card switching is not functional.
Additional hardware buttons are required for memory card switching, which likely requires the availability of two GPIO inputs (for two buttons) and software support.

qxc86, 2022-09-06:
If I ever get builds working properly this was next on my list after extra board support.

g0ldenflash, 2022-09-12:
And maybe these buttons can do other things like creating a new mcr by long press or double click?

dangiu, 2022-09-13:
That's the idea

LobAnovich, 2023-01-21:
In this case, an OLED screen would also be useful, which would display the number of the active memory card

dangiu, 2023-01-23:
Yes, the plan is to get some sort of incremental build with components that can be optionally toggled on and off. This way people that want the chepest possible solution don't have to spend a lot of money, while others that want a full fledged version can have it

realJoshByrnes, 2023-03-19:
It's possible for us to poll the existing button on the Pico/Pico W. Not sure about the buttons on the Zero. I don't believe it's possible to set an interrupt, but I haven't investigated it.

dangiu, 2023-03-19:
I remember looking into that but it was not practical (or straight impossible if I remember correclty) mainly for two reasons:
- We are using both cores simultaneously
- It requires code running from ram which we barely have enough of
- (maybe it even requires suspending interrupts ???)

Don't take my answer for granted tho, I'm writing this from what I remember off the top of my head.
If it's possible it would be the ideal solution tho.

realJoshByrnes, 2023-03-19:
Using both cores simultaneously was an issue I had considered, It should be possible to poll when the MemCard is not active since we have interrupts on that.

That is the next issue; It does require suspending interrupts. (I didn't know that)

https://github.com/raspberrypi/pico-examples/blob/master/picoboard/button/button.c

einso, 2023-08-28:
Hi! Just wanted to check in on this: I recently built some PMC+ as my first experience with ordering parts/PCBs, soldering components etc.
I noticed the buttons on both my units are not working, whether inserted in a PS1 or a PS2 (switching via controller works on the PS1 obviously).
Wanted to know: are the buttons supposed to be working at this point? I see the issue is still open (and, understandably, hasn't been touched in a while), but the ReadMe makes it sound like it should be working.

dangiu, 2023-10-09:
Nope the buttons are not implemented yet, are there on the pcb just for future proofness

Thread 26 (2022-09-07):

Not enough disk space?

NovenTheHero, 2022-09-07:
I am trying to put the blank memory card file on to the pico and it says there is not enough free disk space. Super weird!
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

NovenTheHero, 2022-09-07:
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

Androxilogin, 2022-09-08:
You're overwriting the MEMCARD.MCD file, correct? Just delete it and throw on the new file.

NovenTheHero, 2022-09-08:
No, just installing the firmware, then dragging the memory card file on to the folder.

dangiu, 2022-09-08:
Sometimes windows automatically puts in garbage data to keep track of some stuff... I specifically enlarged the disk above 128KB to make sure this is not a problem but apparently it still seems to be!
Could you test something for me? Can you download the nuke_flash.utf2 from [this page](https://www.raspberrypi.com/documentation/microcontrollers/raspberry-pi-pico.html#resetting-flash-memory) and flash it onto the raspberry to ensure that all the data gets wiped. Then reinstall PicoMemcard and check if the problem is still there

NovenTheHero, 2022-09-08:
I did that and I am getting the same results. This is super weird, and mildly frustrating.

dangiu, 2022-09-09:
You are on Windows 10 correct? Could you try to repeat the same procedure (nuking the Pico flash memory) and flash PicoMemcard from a different os? (maybe a live linux distro such as ubuntu). I'm sorry but I can't to much to debug the issue since it seems to be computer specific.
If anybody else is having this problem please report here your machine configuration.

NovenTheHero, 2022-09-09:
Super weird, I did the nuke, then reflashed it on my linux machine and I think it worked. I will test it out on real hardware later when I get home from work, but tentatively, it is good. At least no issues copying the memcard.

arkwise, 2023-06-02:
hmm weird.. ive tried Mac + linux and windows and the picoMC device shows up but there is no partition or anything,

I flashed the uf2 file fine and the picoMC drive shows up afterwards but there is no partition at all just the device.

when you try to open it or drop file it just says please insert removable media (win) and Mac and linux just say there is no drive/partition available.

I then re-bootsel and dropped my mcr's into this and the uf2 last and all it flashes but no memory card images are available.

dangiu, 2023-06-08:
Which version did you install? You need the plus version for using the micro sd (and of course a micro sd extension and the micros sd itself)

arkwise, 2023-06-11:
> Which version did you install? You need the plus version for using the micro sd (and of course a micro sd extension and the micros sd itself)

the standard version I am not using a SD CARD for storage.

dangiu, 2023-06-12:
> Sometimes windows automatically puts in garbage data to keep track of some stuff... I specifically enlarged the disk above 128KB to make sure this is not a problem but apparently it still seems to be! Could you test something for me? Can you download the nuke_flash.utf2 from [this page](https://www.raspberrypi.com/documentation/microcontrollers/raspberry-pi-pico.html#resetting-flash-memory) and flash it onto the raspberry to ensure that all the data gets wiped. Then reinstall PicoMemcard and check if the problem is still there

Have you already tried to to this?

arkwise, 2023-07-26:
> > Sometimes windows automatically puts in garbage data to keep track of some stuff... I specifically enlarged the disk above 128KB to make sure this is not a problem but apparently it still seems to be! Could you test something for me? Can you download the nuke_flash.utf2 from [this page](https://www.raspberrypi.com/documentation/microcontrollers/raspberry-pi-pico.html#resetting-flash-memory) and flash it onto the raspberry to ensure that all the data gets wiped. Then reinstall PicoMemcard and check if the problem is still there
>
> Have you already tried to to this?

sorry for the late reply, i get an error 1407 on my mac, now i have about 10 of these unit and i get the same results and theyre official units and ive purchased them at different times over the past few years and function fine for other projects so i know theyre mint and ive tried the nuke flash and both version of pico meem to no avail.  the only difference is the nuke remounts the storage after i loaded nuke onto it but as soon as i try to load pico mem its back to square one.

im so keen on this for another project im working on so any help is appreciated mate :)

dangiu, 2023-10-09:
Can you try on a different system? Possibily some linux distribution, not on an apple machine

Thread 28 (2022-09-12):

blinking green light on psx

MrFilz, 2022-09-12:
I build my own picomemcard+ thanks to your project, but i can not get it to work on my playstation. I can write the pico+ firmware to the raspberry, and after a half minute or so the sd card folder opens. It is a 4GB micro sd fat32 formated with 0.MCR and 1.MCR on it. If i plug it into the playstation there is only a blinking green light and no card is recognized... Am i doing something wrong?

dangiu, 2022-09-13:
That's an issue I haven't seen before. So the SD card pops up when the Pico is attached via USB to the computer but does not work on the PSX and keeps blinking? The only thing that comes to my mind is that the microSD is not powered correctly when attached to the PSX, could you share a photo of the build? (in particular the various connections?)

MrFilz, 2022-09-13:
I used a cheap china clone mc for my build. I disconnected all pins from the rest of the board, and attached a pico on top. insulated the bottom of the pico with kapton tape and soldered the pico with its ground points to the board. So in the end every trace beneath the pins of the mc are now ground. This gave me a nice and solid connection. This was for the picomemcard. And it worked flawless after i wrote the firmware and disconnected it save from my laptop! A few weeks later i decided to try picomemcard+ and ordered basically the sd module from your github pictures. I desoldered the  headers and put it on top of the mc housing. Connected all with wires like this:
PIco 33 - ground SD module
Pico 40 - VCC SD module
Pico 21 - MOSO SD module
Pico 25 - MOSI SD module
Pico 24 - SCK SD module
Pico 22 - CS SD module

So the sd card is powered correct if connected to usb. 5V goes in, and the power regulator on the SD module provides 3,28V, according to my multimeter, for the sd card. But the Playstation is only providing 3,3V, so there are only 2,15V on the sd card after the regulator... but you used the same board on the pictures, so i wonder if i am missing something! I also triple checked everything, no shorts to ground on any pin besides ground, no shorts between the pins...

MrFilz, 2022-09-13:
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
![Uploading 1663087192975540925052.jpg…]()

MrFilz, 2022-09-13:
![Uploading 1663087279492413240721.jpg…]()

MrFilz, 2022-09-13:
![Uploading 20220913_184306.jpg…]()

MrFilz, 2022-09-13:
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

MrFilz, 2022-09-13:
I know it looks wild, but everything is connected like i mentioned it, and there is no short!

dangiu, 2022-09-14:
You didn't miss anything, looks like your build was well executed too! Which playstation model are you working with?
There is something that you could test.... If you have another Pico on hand you could: disconnect the power provided by the playstation, then connect the second Pico to USB and bridge the VBUS pins (with a jumper wire) in order to power the other Pico (PicoMemcard+) using USB power while connected to the PSX and see if everything works.

MrFilz, 2022-09-14:
Thanks for your kindness. I have a pal 5502 model with xstation ode installed. Interestingly enough the raspberry pi works flawless as a picomemcard. The issue begins if i try to turn it into a picomemecard+. So i thought the problem must be the sd module itself. And thanks to your guess with the power issue, i tried something else, because i do not have a second pico at hand. Pin 36 on the pico is 3,3V no matter what. It is 3,3V with USB and with the playstation. So i connected pin 36 of the pico with the power rail of the sd module, the right side of c3 on the sd module to be precise! And it worked! The picomemcard+ gives me a solid green, and everything works now! Maybe this helps somemone later! Thank you for this awesome project, and for your help!

MrFilz, 2022-09-14:
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

dangiu, 2022-09-15:
Awesome! I'm glad everything works! :)

Closed 2022-09-15.

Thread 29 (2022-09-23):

Picomemcard+ can't figure why I get a green blinking led

matvenu, 2022-09-23:
I updated my raspberry pi pico from a picomemcard to a picomemcard+ image. While On the picomemcard image, everything worked fine. When I updated it to the picomemcard+ , my pc recognizes the pi as a usb drive. On my psx though, no save files apprear or recognizes that I have inserted a memory card. I got the sample mcr file (which worked fine in the picomemcard) named as 0.mcr, as well the blank save file, named 1.mcr.
I am using the exact micro sd module,as the one pictured on the github page. I solder cs to pin 22, sck to 24, mosi to 25, miso to 21, vcc to 39,gnd to 23 . I used both a 1 and 16 gb cards, formated to fat32 with 512 allocation space.
What else should I do?

dangiu, 2022-09-25:
Can you try connecting VCC to pin 36 (3v3 out)? I used the same connection as you did and everything is working fine for me but some users reported having problems when powering the SD modules with VSYS (only when connected to the PSX which provides a lower voltage than USB) and through testing we figured out it was a power issue

matvenu, 2022-09-25:
I did as you suggested, but I still get a green blinking LED. Maybe I'll try with a 3v module, as the one I already have seems to work only in 5v

matvenu, 2022-09-27:
It was indeed my sd card module. Swapping it for a 3v3 one, the led stays green, as well my psx recognizes it as a proper memory card. It seems that there are variants of the modules that operate only in 5v, even though the sellers claim that function in lower voltages

dangiu, 2022-09-27:
I'm glad everything works :)

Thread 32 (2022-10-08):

My PicoMemcard+ is not reading any images at all? Stuck blinking red

ilickmonkies, 2022-10-08:
Like the title says, I soldered it all up and I know everything with the SD card works because when I put the image for the RP2040 into it it automatically switches to the memory card through the USB-C port. I tried it with the correct version of FreePSXBoot and one I got from PCSXR, both named 0.MCR when I put it in. Do you think this is a software thing or something I did?

ilickmonkies, 2022-10-09:
The non-plus version works fine without the micro SD card module, I tried every format for the micro SD card just to see and that didnt work, so I will triple check the soldering on it, use a voltmeter and if that doesn't work I'm going to try out the DIY one of using the micro sd to SD converter

dangiu, 2022-10-10:
To recap: the Plus version SD works when plugged into the computer (because it pops up and you can transfer the image) but when plugged into the PSX the led blinks red correct?
In that case I believe it's a power issue... Some users have reported that their SD modules do not work correctly when plugged into the PSX (because of the low voltage). One of the solution was soldering the VCC input on the microSD card module to the 3.3V out of the Pico/RP2040-Zero).

ilickmonkies, 2022-10-21:
Sorry for a late reply, I tried this out. SD Module VC in the 3V3 pin hole for the RP2040 and now when I connect it to my PC it does not show up as a USB device. Quadruple checked all the wiring again and it all checks out so I have no idea what's going on. I also seem to be using the same module that you do

dangiu, 2022-10-22:
Ok let's try a new idea... First of all, which playstation model are you using? Second, do you have another Pico on hand?
If the answer is yes, you could try to:
- revert back the wiring so that at least PicoMemcard shows up in the PC (therefore showing that is powered correctly)
- tape away (or disconnect) the pin providing 3.3V from the Playstation
- power PicoMemcard using the second Pico plugged into USB (therefore power goes from USB -> Pico -> PicoMemcard)
At that point I expect it to show up when plugged into a playstation which would indicate that the problem is indeed related to the power the playstation provides.

Zombar3, 2023-05-29:
Hi. I soldered pico zero with sd card, flashed it with PicoMemcard+ and the sd card works on PC, but doesn't work on PS1, tried to flash PicoMemcard not + and also doesn't work on PS1, red LED flashes shortly.

dangiu, 2023-05-30:
You say that you have a "pico zero", do you mean an RP2040-Zero? In that case did you flash the PicoMemcard+.uf2 or the PicoMemcard+RP2040-Zero.uf2?

dangiu, 2023-06-01:
Ok thanks for the info. Since you are able to read the microSD card from PC but it fails when plugged into the PS a possible source of error could be a faulty memory card image. Where did you get your image? What file format is it_

Zombar3, 2023-06-01:
I use MemcardRex for save memory card image. Images in "docs/images" have size bigger then size on pico without sd . Red LED flashes 2 times shortly every time with sd or without.

Zombar3, 2023-06-01:
1. Windows 10
2. I use empty image from MemcardRex
3. Rename image with 0.mcr
4. Now i flash picomemcard blinks red LED, picomemcard+ blinks red LED
5. I try different SD cards 4, 16, 8 GB FAT32 formated

dangiu, 2023-06-01:
Everything seems fine to me... Could you try with a non-empty image as well? On some batches of RP2040-Zero the LED is inverted (green-red) it may be unlikely (but still possible) that everything is working fine but the board still shows the red led.

Zombar3, 2023-06-02:
First blinking green, then constantly blinking red

Closed 2023-06-08.

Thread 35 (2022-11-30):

Controller not working when i plug the picomem+

poyigiygas, 2022-11-30:
I manage to solve the ploblem with the blinking light in the pico and the pc recognoice the sd when i plug the usb in the pico, but it still disconnect the controller, even in the begining before i added the sd module. I put everything in the adapter pcb and it seems the connections are fine.

dangiu, 2022-12-01:
That is very strange, I've never seen that issue. Beside the controller not working, does the psx detect PicoMemcard as a valid memory card? What about if you plug PicoMemcard in the second slot and the controller in the first slot?

poyigiygas, 2022-12-02:
Nope even the status led says all right the ps1 dont recognice the picomemcard+.
When i plug in the second slot Does the same think, even sometimes reboot the console.
If it helps my console has been modded whith xstation and external psu.

dangiu, 2022-12-02:
The fact that it's modded shouldn't make a difference. It may be a power issue since the PC recognizes it. Could you try to do the following:
- tape off the contact that provides power from the PSX to PicoMemcard
- power PicoMemcard using a USB phone charger (do  not use a USB port of a PC otherwise it will enter in transfer mode)
- connect it to the PSX and see if it gets detected

poyigiygas, 2022-12-03:
I give up not working, anyway im going to buy the rp2040 zero and smaller sd adaptor and make it more tidy.
Thanks.

Closed 2022-12-03.

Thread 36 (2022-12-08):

Blinking LED (Pico) - SD Module Power Problems

BRIK1111, 2022-12-08:
I built the original PicoMemcard and everything was fine. I upgraded to the plus using the same SD card module as the guide and receive the blinking LED 99% of the time. Strangely, there have been one or two times when the test memory card file provided does appear.

I uploaded the new uf2 file, the SD card appears through the Pico on my computer for file transfer - so I'm confident the wiring is correct and that the SD card expansion module works. I've also measured the voltage on the module as it's plugged into the PlayStation. 3.5v more or less on the dot. I've also tried the bodge wire fix directly to pin 36 from the other threads. With that installed, I instead measure just under 3v. Could the module not have the power range that's advertised?

Edit: Just want to add that I've tried multiple SD cards.

dangiu, 2022-12-12:
Since the SD card pops up when connected to the PC we know that the SD module and microSD card are both functional. To test whether this is a power issue I would suggest trying the following:
- Make sure that when connected to the PC the SD card pops up
- Tape off the contact that provides power from the PSX to PicoMemcard
- Power PicoMemcard using a USB phone charger (do not use a USB port of a PC otherwise it will enter in transfer mode)
- Connect it to the PSX and see if it gets detected when powered this way

Make sure to only disconnect the power pin and not the ground pin (to the PSX) otherwise they will not be able to communicate properly.
Btw which PSX model do you have?
Sorry for the late reply, let me know how it goes :)

BRIK1111, 2022-12-14:
Yep, taping off the 3.3v and plugging in a charger worked. Does this indicate that the module doesn't work as well on 3.3v as advertised?

The PS1 models I've tried are the SCPH-102 and the SCPH-7502 (both PAL).

dangiu, 2022-12-14:
Yup, that is likely the reason why. Are you able to try with another SD module? Btw could you post a picture of your current one just for reference?

BRIK1111, 2022-12-14:
I've ordered another, this time from a reputable seller as opposed to eBay. I'll report back if it works.

Here is a photo of the original:
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

dangiu, 2022-12-16:
Aesthetically is very similar to the one I was using, I'll see if I still have it and compare the part number of the power regulator.

BRIK1111, 2022-12-31:
I tried another that looked nearly identical (it's just missing the text that says "HW-125") and had the same issue! But again, taping off the 3v contact and plugging in a 5v power supply worked. Pretty disappointing since this was also advertised as specifically being compatible with 3v.

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

So, I bought this since it has a dedicated contact point for 3v power: https://www.jaycar.com.au/arduino-compatible-sd-card-interface-module/p/XC4386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

And it works! It's a shame that it's so big since it used a full-size SD card, but I'll take it as a win.

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

dangiu, 2023-01-03:
I'm glad that at least now it works, I've changed the title of the issue so that it may be easier to find for other people that have the same problem. Happy new year!

dazzaXx, 2024-03-03:
Hi, I just wanted to add onto this issue here as I also had the exact same problem. Instead of looking for another module, I learn't that if you bridge pin 2 and 3 on the regulator, it bypasses it so you can use 3v. Simple fix. All I did to bridge them was put a blob of solder in between them.

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

Closed 2023-01-03.

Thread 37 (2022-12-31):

pi2040-zero can't find micro sd

MrPalloncini, 2022-12-31:
Hi, i soldered and troubleshooted everyting  by following the readme, howewer, when i connect the rp2040-0 the the pc after i flasched it, the sd won't appear and it flash red. Tryied also with a raspberry pi pico and it works, is there any problem with the fw maybe?

Thank you for thia awesome project

dangiu, 2023-01-03:
No, the firmware has been tested by many people, normally when the SD card does not appear is related either to a power problem with the module or due to the card not being formatted in FAT32. Since you said that it works fine on the pico I think it may be due to a power problem, make sure to double check your wiring and the voltage the module requires... It could be that the pico and rp2040-zero are outputting slightly different voltages.
Also check out issue #36 which discusses power related issue with modules.

seanchapman, 2023-01-19:
I'm having this issue too, as well as the inverted red and green LEDs (on a recent RP2040). Firmware v1.0.0 works but v1.0.2 does not.

dangiu, 2023-01-20:
About the LED problem, have you looked into issue #38? It seems like you are not the only one having it.
Regarding the disk instead I have no clue what may be going on? Can you provide some more info (what works on which platform (OS) and what does not with the different firmware versions)? By chance are you able to debug the program and step through the code?

seanchapman, 2023-01-21:
I've just tested the inverted LED build and actually that's working great for me now! LED is the correct colour, saves are loading on PSX and I can see the microSD in Windows.

I tried v1.0.2 again as well and that seems to work now too so I'm not sure what happened with that.
Previously I was using v1.0.0 and having the issues with the LED turning off.

I'm not familiar with pico debugging but it seems like the inverted build is working best for me.

dangiu, 2023-01-23:
Awesome, the LED issue was fixed in between versions. I don't know what happend that caused the inversion, they likely changed something in manufacturing.
Anyway I will now close the issue since the problem has been solved.

Closed 2023-01-23.

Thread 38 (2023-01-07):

Rp2040 zero with another led

Alex12DEUT, 2023-01-07:
Hey
I received a new batch of rp-2040-zero , i think they have modified the led reference , or maybe just a mistkake from factory
But the red and green colors are "reversed" , when all is fine the picomemcard will show a fixed red color ( instead of green ) , and when it have something wrong it will have green color blinking ( instead of red ) but all is working fine
All the small batch is like that
The issue is same if put picomemcard uf2 ( no sd card ) and picomemcard+ ( with a sd card module )

have someone see that before?
maybe a small uf2 update will fix it? Certainly need inverse the values for red and green

thx

dangiu, 2023-01-13:
That is one of the most bizzare thing I've ever heard! In the next days I'll compile a modified version as soon as I get a chance so you can try it out :)

Alex12DEUT, 2023-01-13:
Ok thank you i will tell you if it work for picomemcard and picomemcard+ If just inverse code for red/green in your code

dangiu, 2023-01-18:
[InvertedRedGreenBuild.zip](https://github.com/dangiu/PicoMemcard/files/10443507/InvertedRedGreenBuild.zip)
Here are the build with the inverted led both for picomemcard and picomemcard+.
Let me know if it works

Alex12DEUT, 2023-01-20:
Your files are in .elf extension , not .uf2 i cannot put them on my rp2040 :(

dangiu, 2023-01-20:
[PicoMemcard.zip](https://github.com/dangiu/PicoMemcard/files/10464148/PicoMemcard.zip)
My bad, here are the .uf2

Alex12DEUT, 2023-01-20:
i have test for both it ok for the led , now its green when all if fine and red where it have something wrong thx :)
but when make the test i have find another issue with the picomemcard ( not the + ) when you copy a save from normal card to picomemcard ( with ps1 or a ps2 ) if the file is too big its fail ( 5 blocks )
i have test to make a memcard.mcr with 15 block of save ( full ) on computer and inject it , picomemcard see all save , and if try to delete one = fail
i think it have a memory management problem in the code of picomemcard :/

dangiu, 2023-01-23:
Thanks for the heads up, I'll look into it

Alex12DEUT, 2023-01-23:
i have find another thing with the picomemcard ( not + ) when you copy a ''big save '' , like theme park world game  ( 5 blocks )   from ps1 or ps2 browser from genuine sony card to picomemcard , the copy fail

seanchapman, 2023-02-03:
I've added a switch to invert the colours in #41 BTW :)

Davis-A, 2023-07-07:
Looks like i've also got the inverted colours!  I've never soldered before so i thought i must have screwed something up and was looking for information on errors, it started working and i found this issue.

Here's a video: https://www.youtube.com/watch?v=m8Bqp1F9n0Q

PSXmanCZ, 2024-07-03:
Hello

Please I would like to ask on the PCB board there are three points for LEDs.  And I didn't find any more precise information or photo about it. Can I ask you what type of LED is suitable for this type of project?

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

Thank you
And I must thank the author for the great work I like this project very much.

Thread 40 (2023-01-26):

PMC+ Doesn't work with image above 10.MCR

LobAnovich, 2023-01-26:
When trying to create more than 10 memory card images on PicoMemeryCard+ via SPS1(One), memory cards higher than 10.MCR number are not created.  In the case of creating an image of a memory card 11.MCR and higher through a PC, when you try to switch further than 10 memory cards, the switch does not occur.  The indicator shows that the 10.MCR card is the last one in the list

UPD:
Tried after a while.  If you keep start + select constantly pressed, then switching between all existing memory cards, even above 10.MCR, occurs normally.  When trying to create a new memory card above 11.MCR, a 12.MCR card was created once.  Above new maps are not created

dangiu, 2023-02-05:
Okk I'll look into it, thanks for the update!

realJoshByrnes, 2023-03-19:
Able to reliably reproduce this issue which limits PicoMemCard+ to 10 memory cards.

Memory cards 0.MCR to 9.MCR work fine.

memcard_manager_create(10.MCR) != MM_OK

realJoshByrnes, 2023-03-19:
Additionally, once the 10.MCR is created, future attempts to create the 10.MCR fail due to it existing and being invalid.

whitezombie2000, 2023-03-23:
I can confirm all the above behavior with a PicoMemeryCard+.

realJoshByrnes, 2023-03-24:
@whitezombie2000 Great feedback, which has identified another bug - https://github.com/dangiu/PicoMemcard/issues/56

I have added firmware which is compatible with PMC+ for Pico/Pico W (not the rp2040-zero) and has the creation fix at https://github.com/realJoshByrnes/PicoMemcard/releases/download/v1.0.22/PicoMemcard.zip if you'd like to try it.

Whilst it should allow you to create more memory cards, it doesn't change the sorting order for cards.

whitezombie2000, 2023-03-24:
Sorry I can't test it because I believe mine is built with the rp2040-zero.

realJoshByrnes, 2023-03-24:
@whitezombie2000 No problems. It's probably worth subscribing to issue #56 also, which is the order bug you've identified.

I've submitted a PR #55 which, if merged, will fix the card creation issue, just waiting on a response from @dangiu

whitezombie2000, 2023-03-24:
I just tried your file so it must be based off of the rp2040. I was able to create 12 memory cards.

LobAnovich, 2023-03-24:
Due to the small size and the ability to place the entire project inside the case of the original ps1 memory card, I had no doubts about choosing the rp2040.  Both my DIY picomemcard + and the card from China have a problem

LobAnovich, 2023-03-24:
> I just tried your file, it worked without any issue, so it must be based off of the rp2040. I was able to create 12 memory cards.

Only 12?

whitezombie2000, 2023-03-24:
> > I just tried your file, it worked without any issue, so it must be based off of the rp2040. I was able to create 12 memory cards.
>
> Only 12?

Is 20 enough for you? :)

realJoshByrnes, 2023-03-24:
> I just tried your file, it worked without any issue, so it must be based off of the rp2040. I was able to create 12 memory cards.

@whitezombie2000 It's based off PicoMemCard+, but I haven't got an rp2040-zero to test.

> Due to the small size and the ability to place the entire project inside the case of the original ps1 memory card, I had no doubts about choosing the rp2040. Both my DIY picomemcard + and the card from China have a problem

@LobAnovich The rp2040-zero is a nice size. Are you building the image yourself? Feel free to start a new issue and we can see if we can work out what it is @LobAnovich as I have had success with Pico / Pico W / PSXMemCard

> Only 12?

I believe @whitezombie2000 meant they could create 12 successfully, where they couldn't previously.

whitezombie2000, 2023-03-24:
> > I just tried your file, it worked without any issue, so it must be based off of the rp2040. I was able to create 12 memory cards.
>
> @whitezombie2000 It's based off PicoMemCard+, but I haven't got an rp2040-zero to test. Did the colored LEDs work?

Yes I know the China one is based off the PicoMemcard+ but I wasn't sure if they were using a rp2040 or rp2040-zero in their design. Since your file worked it must be using a rp2040 in their design. Yes the LEDs work.

Hmm...after creating 20 cards it's defaulting to card 7.MCR upon the first inserting into the PS1. This must be related to the order issue.

realJoshByrnes, 2023-03-24:
@whitezombie2000 Remembering the last card was a precious commit. PR relating to creating new MCs has now been merged (fixed on future builds)

Closed 2023-03-24.

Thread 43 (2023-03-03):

Pico is not detected

Nacheras, 2023-03-03:
When it try to flash "PicoMemcard+.uf2" , windows detects the pico when pressing the BOOTSEL button, I copy the .uf2 archive and then it is supossed to show the Pico as a usb device to copy the mecard.mcr, but it doesn´t. It just show me the device as a letter. I have tried with different computers.
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
What could be the problem?

dangiu, 2023-03-07:
Have you soldered the SD card module and inserted the SD card? PicoMemcard+ works only with the MicroSD SPI module, otherwise you need to use the non-plus version (just PicoMemcard).

Closed 2023-03-07.

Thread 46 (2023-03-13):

PSXMemCard

realJoshByrnes, 2023-03-13:
I was having a little bit of a look around and found [PSXMemCard](https://www.aliexpress.us/item/1005005071752501.html), a commercial pre-built implementation of this software
* [User Manual](https://www.bitfunx.com/wp-content/uploads/2022/12/psxmemcard-usemanual.pdf)
* [TradeMark Application](https://branddb.wipo.int/en/quicksearch/brand/US502022097654216)

I guess I was just curious if this is related to the project, or just using the code from the project?

dangiu, 2023-03-14:
Yes in their page it clearly refers to this project... I didn't know they were trying to trademarke it... A bit scummy if you ask me

realJoshByrnes, 2023-03-14:
I agree, it does seem scummy. But to be fair, the license is permissive, and they're trying to register "PSXMemCard" rather than "PicoMemCard", and it's also just the name rather than the device.

I guess I was just wondering if they contribute back to the project, in a similar way that [BlueRetro](https://github.com/darthcloud/BlueRetro) seems to have set-up. I've ordered one from RetroScaler to have a look.

dangiu, 2023-03-15:
Oh! If they are just registering the name I have nothing against that.
So far I have not been contacted by anybody so I don't think they are interested in contributing.

realJoshByrnes, 2023-03-15:
I was just curious, that's all. If you'd like I'm happy to share info regarding the device once I get it (from China, could take a while!).

To be honest, I've been wanting to make an SD to MemCard project for a while (years), but I was considering doing so in Typescript. With the cost of the rp2040, a C/C++ project is probably the best way to go (was going to use an ESP32 previously), you've done a great job with this project and I'll probably contribute more in the near future.

realJoshByrnes, 2023-03-16:
Since you have one, would you care to share your thoughts on the PSXMemCard @LobAnovich ? Obviously it looks good, but how does it function? Does it have any external buttons for updating etc?

LobAnovich, 2023-03-16:
The Chinese pico memory card is 100% created by the picomemcard + project with the same features and disadvantages.  It does not have a screen, mechanical buttons for switching memory card images and it does not remember the last active memory card image

realJoshByrnes, 2023-03-22:
I've just received the PSXMemCard in the mail, and I'm pleasantly surprised.

I was expecting a MicroUSB, it has USB-C.
I was expecting no way to update, it has a (hidden) button next to the USB port which works in the same way it does on a Pico.

To press the button, you'll need a a SIM card removal tool or similar.

```
RP2040 - Revision B2
25016JVS1Q 2MB Flash Storage
```

realJoshByrnes, 2023-03-22:
Image of the boarcd: https://photos.app.goo.gl/x3GLaLk12rBLKvBS8

The following parts are slightly cropped:
`SW1` Micro-switch that enables firmware upload
`P1` USB-C Port
`D2` Red LED (Light Emitting Diode)
`J9` MicroSD reader

dangiu, 2023-03-24:
That seems to be pretty well made! I believe that some hardware changes will need to be implemented for the project to support PS2 memory cards but hopefully they'll make new revisions.

amak79, 2023-05-22:
The PSXMemCard would need the `PicoMemcard+RP2040-Zero.uf2` image when updating?

realJoshByrnes, 2023-05-22:
> The PSXMemCard would need the `PicoMemcard+RP2040-Zero.uf2` image when updating?

Hi @amak79, I think you're after the [PicoMemcard+.uf2](https://github.com/dangiu/PicoMemcard/releases/download/v1.0.2/PicoMemcard+.uf2) image for this device.

amak79, 2023-05-23:
Thanks @realJoshByrnes. Would it be possible to update the device with the wrong image, and if so would it be recoverable?

realJoshByrnes, 2023-05-23:
@amak79 If you have any issues, you can hold the BOOTSEL button in when you apply power, and reflash.

dangiu, 2023-05-23:
I have no clue, it would depend on how they wired the components together... Do they mention it on the product page? Anyway you can try the RP2040-Zero and if it doesn't work try the Pico one... It shouldn't really be a problem.

Ceep0rt, 2023-10-02:
Good day! I got a curious situation with PSXMemCard. Just purchased one from AliExpress and after trying to boot into memcard menu my PSone just got black screen and after some moment rebooted. Just to specify, after inserting for the first time PSXMemCard and trying to boot PSone into the Memory Card menu, the menu (where you choose between Memory Card and CD Player) itself showed up for a couple of seconds and before I could even press any button the black screen came up, some seconds later PSone rebooted and the only thing I got was the main white screen with SONY logo, without music. From now on when I'm trying (with or without PSXMemCard) to turn on the PSone, the first thing I see is a black screen for like 10-15 seconds, then the SONY white logo appears without music and stays like this as much as you want.

Connecting to PC, the only thing you can explore is a 0.MCR file.

I disassembled my PSone for the first time, previously it belonged to the friend of mine, and discovered some modifications, not sure what kind. I assume something to bypass the original CD requirements.

Any idea? Any suggestion?

- 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
- 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
- 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
- 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

dangiu, 2023-10-09:
Sorry but I have no idea... I'm not associated in any way with the products on aliexpress. In addition the modification could have unforseen effects... Just to confirm, you have used it before (without aliexpress picomemcard) and it worked fine?
I'll leave this issue open for a bit to see if anybody has had similar experiences and can answer but my feeling is that this is not related to the project unfortunately.

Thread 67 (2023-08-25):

Please insert disk into usb drive error after installing picomemcard software on picomemcard +

D3iv, 2023-08-25:
I've tried solving this problem myself to no avail, couldn't find anything on the internet regarding this issue. Checked all of my solderjoints, perhaps I'm missing a library or a driver of some sorts?

ste94pz, 2024-05-09:
Same problem here on rp2040-zero, microsd formatted correctly, recompiled with develop pico-sdk. I'm using this microsd module with the AMS1117 regulator bypassed and connected to the 3.3v pin of the rp2040-zero.
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

dangiu, 2024-05-10:
To me it seems like your setup is correct.
You have included the fix mentioned in [raspberrypi/pico-sdk#1304](https://github.com/raspberrypi/pico-sdk/issues/1304) correct?
Maybe you could try to swap the microsd module for a different one just to make sure that it's not faulty.

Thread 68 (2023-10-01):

[INFO] Quirks of the Aliexpress PicoMemcard

wired-filipino-owl, 2023-10-01:
@dangiu, please pin this issue if you think it's worthwhile to learn more about this board.

Owners of this device, please reply with any additional information you have about this board!

BitfunX on Aliexpress sells a PicoMemcard ready to go, including a no-name 512MB microSD card. Here is some things I was able to figure out about this device.

The status LED is RGB. I can see three lines going to it on the board, plus ground I assume. LED is labeled D2. See the photos of the board.

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

Now let's see what GPIO those pins correspond to, I counted 5 pins from the left edge, which would make the lines connected to physical pins 35-37. Those correspond to GPIO 23-25. See the pinout from the RP2040 datasheet:

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

Quality of the device:
I think it's worth the $15 USD. Winbond flash chip, quality molded plastic case, and push-eject SD card slot. Also, the BOOT/BOOTSEL button is accessible without taking apart the case, just use a paperclip or similar sized object to press the button.

wired-filipino-owl, 2023-10-01:
I was able to flash the MicroPython firmware and run an RGB example program on my PicoMemcard. The pins hooked to the RGB LED are indeed GPIO 23-25.

dangiu, 2023-10-09:
Great investigation!

dangiu, 2023-10-09:
As @wired-filipino-owl pointed out in #56 Release 1.0.2 for the Pico seems to work correcly on this board

MrPalloncini, 2024-06-29:
The release 1.0.3 work with the Bitfunx memorycard without any issue, the problem was that the new led code for the pico_w broke the compatibility. i've been able to restore it by adding some #ifdef to the config.h. It's also worth noting that on the back of the card there are 3 pins exposed which are the pio0, pio1 and gnd. They are useful for debugging purpose since i used it all the time to print .
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

amak79, 2025-02-11:
Does anyone know of a source for the boot button (`SW1`)? Mine snapped off with little force and now it can't be updated unless I temporarily bridge the two pads.

wired-filipino-owl, 2025-02-14:
@amak79 as long as the pads are still intact, you should be able to find an equivalent search at an electronics distributor such as Mouser. Here's a link with some filters to get you started: https://www.mouser.com/c/electromechanical/switches/tactile-switches/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

I'll add another comment if I find the exact switch.

amak79, 2025-02-14:
Thank you very much.

I initially looked at [JLCPCB parts](https://jlcpcb.com/parts) but was overwhelmed with the thousands of buttons and switches.

amak79, 2025-02-18:
I couldn't find the switch on Mouser. I asked Bitfunx and surprisingly they replied with the link to the correct switch: https://www.lcsc.com/product-detail/tactile-switches_sm-switch-smg-10-h035b0_C29781355.html

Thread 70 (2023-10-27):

RP2040 generic

madmai, 2023-10-27:
I use this how rp2040 [https://imgur.com/8IVB1Z4](url) and no Works, sometimes blue led blinking not ever
and this works randomly sometimes green led fixed sometimes blinking this is original rpi pico[https://imgur.com/HICGgex](url)

what can i do for 2 versions works, pi pico original sometimes works, but the black one, never works, anyhelp is apreciated, thx

dangiu, 2023-10-30:
To solve this I will need more information:
- Which version of picomemcard are you trying to use?
- Which devices are you using with it? You mentioned one original pico and one black, I need more informations about the second one.
- Have you checked the soldering joints with a continuity tester to make sure they are good?

madmai, 2023-10-30:
[https://imgur.com/NCuncBR](url) now i'm using this, and yesterday works, but now blinking led green in original pi pico, with release pico 1.0.2, before i test too 1.0.3 pico, but now version i use is 1.0.2 pico, i have those too [https://imgur.com/ovCDs9p](url) i build 2 memcards adapter to plug in psx, and when i have i test 3 models, with 1.0.2, black one, purple on and pico original, i tell something when i have, i thing in the one i have build the conectivity is not the problem sometimes works, sometimes blinking in pico original, now is blinking, if you want tellme in pm too, thx, for your attention

dangiu, 2023-10-30:
I'm sorry but I'm having trouble understanding everything. From what I can tell if you are experiencing intermittent issues (working for a bit than not working) I think the most likely cause is some sort of bad connection

madmai, 2024-04-25:
I think i need 2 red cables vcc, it's correct? someone can explain me, how to feed vcc 3.3v micro sdcard , and how to feed pi pico vcc voltage, please explain me scheme of feed voltage map in pico drive and micro sd, i think this is the problem, only voltage feed schema, for disolve my dudes... thanks for advance to all people, thx again

dangiu, 2024-05-03:
I believe the adapter from [this picture](https://imgur.com/NCuncBR) needs 5v on VCC (and does its own conversion down to 3.3V) so you need to connect the Pico VSYS (pin 39) to it. Question: the Pico is powered by the PSX right?

madmai, 2024-05-03:
i think the psx 3.3 v memcard port not works properly only do 1.5v(maybe with tests brokes), i think i repaired to 3.3v memcard port now, but tell me how i have to connect pi pico voltage and sd voltage i have others sd ports works in 3.3v, if you can tell me how i have to connect pi pico and sd card, the scheme vcc connections in pi pico, thanks in advance, in the project image, [this image](https://github.com/dangiu/PicoMemcard/blob/pmc%2B/release/docs/wiring-pico.svg), tell me how to connect pi pico to receive 3.3v and how connect out to sdcard port, i don't understand in previous image please, can you specify me, where connect from mc 3.3v to pi pico and sd port voltages vcc port?, first of all, thanks a lot for your attention and replies, thanks again, and my apolyge for my english, i'm spanish.
i wait a reply, thx

madmai, 2024-05-06:
> I have trouble understanding everything but here is what you need to connect: To power the pico: MemoryCard 3.3v <--> Pico VBUS (40) To power the SD module (if it has it's own regulator): Pico VSYS (39) <--> SD VCC To power the SD module (if it needs 3.3v): Pico 3V3(OUT) (36) <--> SD VCC Ground must be in common for everything (GND on PSX, GND on Pico, GND on SD)

ok a lot of thanks, when i have time, i try, again thanks

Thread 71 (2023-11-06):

RP2040-Zero not recognized as a storage device (Windows 11)

Manghao, 2023-11-06:
Hello, I have an RP2040-Zero, I transferred the file PicoMemcard+RP2040-Zero.uf2 on it by pressing well on the BOOT button before connecting it to the PC, I have the notification sound windows which dismounts and remounts the USB device, but I do not have access to the storage of the RP2040. I do have PicoTM Mass Storage USB Device

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

Manghao, 2023-11-09:
I have the same problem on MacOS, the RP2040 disconnects with an ejection error, although it is present but not displayed in storage.

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

dangiu, 2023-11-11:
3 things you should check:
- is the SPI sd module installed correclty (wires and connections)?
- is the microsd card inserted?
- is the microsd card formatted in FAT32 (only format currently supported)?

dangiu, 2023-11-21:
Thanks for the info @carmax91. The related PR is not merged yet but I'll patch it myself for the next release at least until it gets merged.

NDR008, 2023-12-09:
Is there a manual way I can work around this issue?

ste94pz, 2024-05-08:
Hi, any news about this problem?

danvx6, 2024-11-15:
I've also run into this issue.

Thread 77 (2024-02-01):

RP2040 Zero not recognized

jeffbrl, 2024-02-01:
I'm almost certain my issue is the operator induced rather than the software.

I built three RP2040 zero-based PicoMemCards loaded with https://github.com/dangiu/PicoMemcard/releases/download/v1.0.0/PicoMemcard_RP2040-Zero.uf2. I am using dangui's v1.3.1 PCB and his enclosure. I loaded the non-blank memory card image from this repo. The name is unchanged. Using the diagrams in the README, I verified continuity from the Zero's pins to the pads on the PCB that interface with the PSX.

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

I am inserting the PicoMemCard with the Zero side facing down.

On all three PicoMemCards, the PSX does not recognize the PicoMemCard. The green LED is lit.

I'm at a loss for how these the zeros could have continuity and the correct software loaded and not function properly. I feel as though there is something I am doing wrong that may be obvious to others but not me.

May I get tips for additional troubleshooting?

Haldrie, 2024-03-31:
It looks like you have some cold solder joints in the picture. It may have continuity but maybe the connection is weak and not keeping up with the PS1's timings or when you tested continuity your probe was making contact with the pad under the RP2040 and not just to the RP2040 itself or pushing your probe made contact where there isn't one if no pressure is put on it. Try adding some flux and reflowing the solder and see if that helps any. The attached picture is one of 5 that I have built using the microSD module and the pads you see soldered are the only ones that are connected to anything. Pins 26-28 are connected to the button pads on the board for use with PicoMemcard+ code but I recently learned from the developer that he never added any code to take advantage of them...yet.

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

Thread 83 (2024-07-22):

Controller doesn't work when plugged in

Seva167, 2024-07-22:
I have a SCPH-7000 Japanese console and aliexpress Psxmemcard, when i try to plug it in bios acts like controller is unplugged, when already in memory card menu, it still doesn't work.

Is this aliexpress memcard issue or japanese bios issue?
Tried different memcard and controller slots.

Blank firmware still triggers this issue.

realJoshByrnes, 2024-07-23:
I can't imagine that it would be an incompatible BIOS, but it's always a possibility (the same is true for the controller)

What do you mean by blank firmware? Did you flash the device?

Have you tried with/without the SD card? Does this make a difference?

I suspect that the device may be defective, but it could also be a software issue. As we don't know what's on the device, can you try flashing a different version of PicoMemCard on it?

Seva167, 2024-07-23:
Tried most of the versions.
Blank firmware is firmware that disables all gpio and goes into infinite loop.

SD card makes no difference except blinking LED indicating error.
RP2040 appears to be working, and i'm not sure how it is even interferes with the controller.
Even when power pins are blocked it still interferes, maybe some pins are shorted somewhere.

realJoshByrnes, 2024-07-23:
> maybe some pins are shorted somewhere.

Once I read that you're actually installing blank firmware (ensuring you didn't mean a clean PMC install) my first thought was that you have a short.

If you've got a multimeter you could test for continuity between pins.

I'd get in touch with the seller. Hopefully it's just one bad device, and not a bad batch.

Seva167, 2024-07-24:
Looks like in my case pin 2 is shorted with pin 6

Seva167, 2024-08-11:
Got a refund from aliexpress, ordered a replacement, works now.

Closed 2024-08-11.

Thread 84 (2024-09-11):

What about the LED indication in version 1.0.3?

PSXmanCZ, 2024-09-11:
I looked on various threads to see how it is with the LED indication I found some descriptions that it changes red for orange if I understand correctly to make the unsynchronization more obvious.

Then I noticed that for some of the newer versions of the RP2024 you applied a swap of red and green. And I must have bought an older version of the RP2040 on Aliexpress this year or they got something wrong in that copy.

I've always used opaque boxes so I didn't notice it but now I've played around with the design. So that I know the status of the memory card. And now my card is glowing red all the time and working as it should and when something is being saved it glows green. Even the error message indicates green. It's confusing.

I have no programming experience and don't want to burden you. I would just like to ask you which parts of the code I can change for version 1.0.3 and swap the colors (green with red) for my RP2040 model? I guess in the led.c file ? I just don't know which line(s).

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

How to compile it into the final .uf2 file I can find somewhere on YT or google. That's how I'm used to educate myself.

Thank you for your great work.

wired-filipino-owl, 2024-09-29:
You're correct that `led.c` is what controls the LED colors. For compiling the project into a `.uf2`, consult the official Raspberry Pi documentation: https://www.raspberrypi.com/documentation/microcontrollers/c_sdk.html#sdk-setup and https://datasheets.raspberrypi.com/pico/getting-started-with-pico.pdf

There's an updated fork of this project by MrPalloncini that adds some features and bugfixes here: https://github.com/MrPalloncini/PicoMemcard. This includes my PR to add support for the LED on the BitfunX/Aliexpress PicoMemcard device. I believe the LED colors have been changed back to match the README table in that version. As you said you have limited programming experience, I suggest you check out MrPalloncini's version first, before trying to make your own.

Warning: Being Pedantic Below
> The RP2040 is the chip itself, which doesn't change regardless of what RP2040 board you get. What I believe you were asking is what board configuration you have, which is kind of hard to figure out without looking at the board or the store listing.

PSXmanCZ, 2024-10-01:
Thank you for the information. I'm going to study. I know about the MrPalloncini project. But unfortunately he focuses more on Bitfunx and Game ID also got xstation it would be interesting. But unfortunately no relase works for me on my picomemcard+ (PR2040) or on the rasbery pi pico version. With version 1.0.4 the memory card lights up but can't find the MCR image even if I edit the index.txt as instructed. I am therefore referred to the original project. The author of the readme file states that he only tests on Bitfunx and does not have PicoMemCard+. But thanks a lot anyway.

PSX-MAN, 2025-08-09:
It would probably help, but unfortunately I don't have enough experience in compiling code. That's where my efforts failed. It's complex, and I had to install a lot of programs (plugins), even though I went through all the various tutorials. It seemed like it wasn't that difficult, but when you don't know what you're doing and why, it's hard to find where you went wrong when the compilation ends with a generic error.

What would you recommend for compiling? I tried a combination of Visual Studio Code + various plugins. Maybe I'll try again sometime; I don't like to give up. At the same time, I don't want to bother people who are willing to do such amazing projects in their free time. All I need is a little tip, and I'll try to find out more about it myself.

Thank you.

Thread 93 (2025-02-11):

Uf2 built from source does not behave as released uf2 on RP-2040-Zero

HashakGik, 2025-02-11:
Let me first say this project is awesome! Thanks a lot for your efforts.

I am having some difficulties in compiling uf2 binaries for RP-2040-Zero from source. Namely, the provided binaries work as expected, but checking out the source code and compiling it produces a non-working binary.

I  am using Visual Studio Code on Windows, with the Raspberry Pi Pico and CMake Tools extensions.
The project is configured to use Pico SDK version `1.5.1` (versions 2.x have changed some function names and do not compile successfully), board type `pico_w` and the repository is cloned  with `git clone https://github.com/dangiu/PicoMemcard --recursive`.  The project is  configured  to build only the `PicoMemcard` target, as controller_simulator and memcard_sniffer cannot be built due to errors in the included no-OS-FatFS-SD-SPI-RPi-Pico library).

In `config.h` I have selected the correct board (uncommented `#define  RP2040ZERO`,  and commented out `#define  PICO`) and fixed two minor syntax errors:
- in `src/led.c` line 29:  replace `#elsif`  with `#else`
- in `no-OS-FatFS-SD-SPI-RPi-Pico/FatFs_SPI/sd_driver/sd_spi.c` line 93:  replace `u_int8_t` with `uint8_t`

The  executable compiles  successfully and it can be upload to an RP-2040-Zero PicoMemcard+ (bought from ebay so I am confident the hardware is fine) which works with your released uf2 files, but not with mine.
When using my version, the PlayStation does not recognize the memory card, neither in the BIOS  menu, nor in game,  however LEDs display an interesting behavior, which suggest that the microSD content is recognized,  but then something  else does not work as expected:

| Event | Dangiu uf2 behavior | My uf2 behavior |
|---------|--------------------------------|-------------------------|
| No microSD inserted | Blinking red LED, PS does not recognize MMC | Blinking red LED, PS does not recognize MMC |
| Empty microSD formatted Fat16 | Blinking red LED, PS does not recognize MMC | Blinking red LED, PS does not recognize MMC |
| Empty microSD formatted Fat32 |Blinking red LED, PS does not recognize MMC | Blinking red LED, PS does not recognize MMC |
| Fat16 microSD with 0.MCR | fixed green LED, PicoMemcard generates missing  files, PS recognizes the MMC | Fixed green LED, PicoMemcard  does not generate LastMemcardIndex.dat, PS does not  recognize MMC  |
| Fat32 microSD with 0.MCR | Fixed green LED, PicoMemcard generates missing  files, PS recognizes the MMC | Fixed green LED, PicoMemcard  does not generate LastMemcardIndex.dat, PS does not  recognize MMC  |
| Fat32 microSD with 0.MCR and LastMemcardIndex.dat | Fixed green LED, PS recognizes the MMC | Fixed green LED, PS does not recognize MMC |
| Start+select+etc. button presses | Blue LED flashes, MCR index changes correctly | Nothing happens  |

This behavior is exactly the same as the compiled binaries of MrPalloncini's fork (downloaded from their releases), so my guess is that they are also compiling the RP-2040-Zero target incorrectly.
This happens checking out every release from either repository (dangiu's and MrPalloncini's), therefore it seems  a compilation problem, or a problem with the no-OS-FatFS-SD-SPI-RPi-Pico submodule.

In general, I believe it would be greatly beneficial to add compile instructions for RPi-Pico and RP-2040-Zero on the README file.

leafy-psx, 2025-08-08:
Hi, I believe board type should be waveshare_rp2040_zero, and are you building from the pmc/release branch? I can try to compile later.

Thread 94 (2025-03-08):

Picomemcard Zero (no + version): problems when copying MEMCARD.MCR file in Linux

madmalkav, 2025-03-08:
If I copy the MEMCARD.MCR file in Linux, it seems to copy OK (same md5 and all) but after you dismount the drive, the file is corrupted. It works OK if I copy the file from Windows.

madmalkav, 2025-03-29:
I tried and didn’t solve the problemEl 29 mar 2025, a las 13:02, HashakGik ***@***.***> escribió:
  Have you tried manually synchronizing I/O before removing the drive?
In general files are not moved immediately when we do a copy-paste, and they are actually written at a later stage. Windows and Linux have different policies about when this should happen,  and the "safe eject" feature is there exactly to ask the operating system to hurry up and commit all the postponed operations. Sometimes though Linux takes a long time and you end up disconnecting your device under the impression your files were actually copied, while in fact they were still uncommitted.
You can force a manual synchronization by opening a terminal, typing sync and waiting for it to finish (it will not print anything, but the terminal will not accept new commands until it finishes). After a sync you can safely eject your drive.—Reply to this email directly, view it on GitHub, or unsubscribe.You are receiving this because you authored the thread.Message ID: ***@***.***>

HashakGik left a comment (dangiu/PicoMemcard#94)
Have you tried manually synchronizing I/O before removing the drive?
In general files are not moved immediately when we do a copy-paste, and they are actually written at a later stage. Windows and Linux have different policies about when this should happen,  and the "safe eject" feature is there exactly to ask the operating system to hurry up and commit all the postponed operations. Sometimes though Linux takes a long time and you end up disconnecting your device under the impression your files were actually copied, while in fact they were still uncommitted.
You can force a manual synchronization by opening a terminal, typing sync and waiting for it to finish (it will not print anything, but the terminal will not accept new commands until it finishes). After a sync you can safely eject your drive.

—Reply to this email directly, view it on GitHub, or unsubscribe.You are receiving this because you authored the thread.Message ID: ***@***.***>

leafy-psx, 2025-08-09:
Have you copying tried as root or using sudo? Possibly a USB device permission. Possibly need to edit your udev rules to allow it.

leafy-psx, 2025-08-10:
To anyone else with this issue. I had trouble until I;  logged in as root, unmounted the Pico MC, as root mounted it again to /mnt/pmc, as root copied the memcard.mcr. I'm still trying to figure out the best/etc/udev rules.

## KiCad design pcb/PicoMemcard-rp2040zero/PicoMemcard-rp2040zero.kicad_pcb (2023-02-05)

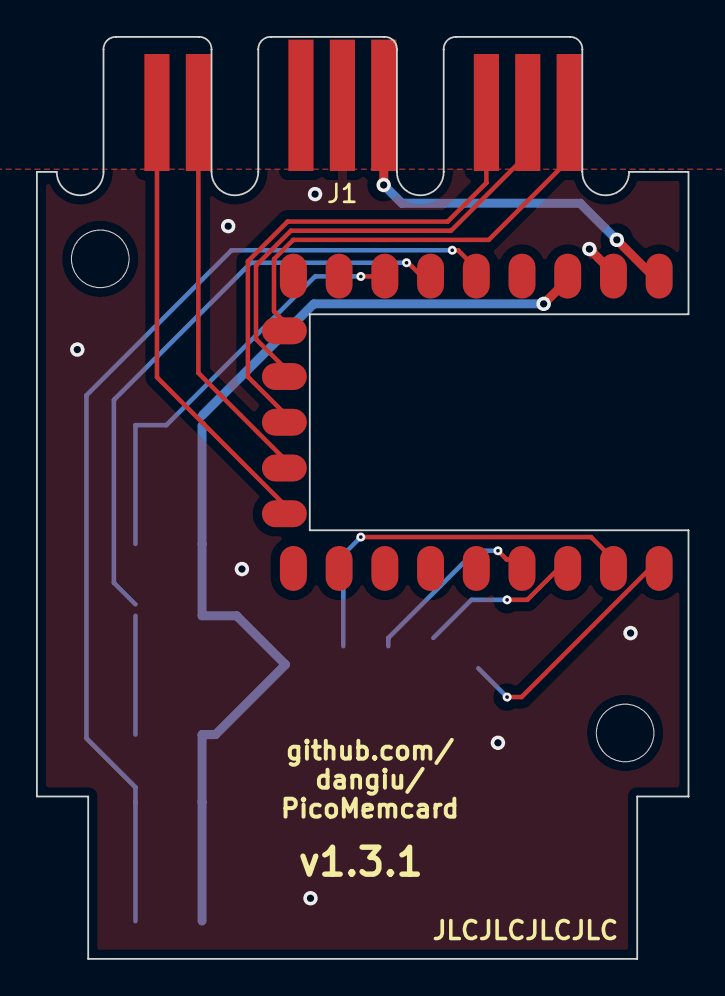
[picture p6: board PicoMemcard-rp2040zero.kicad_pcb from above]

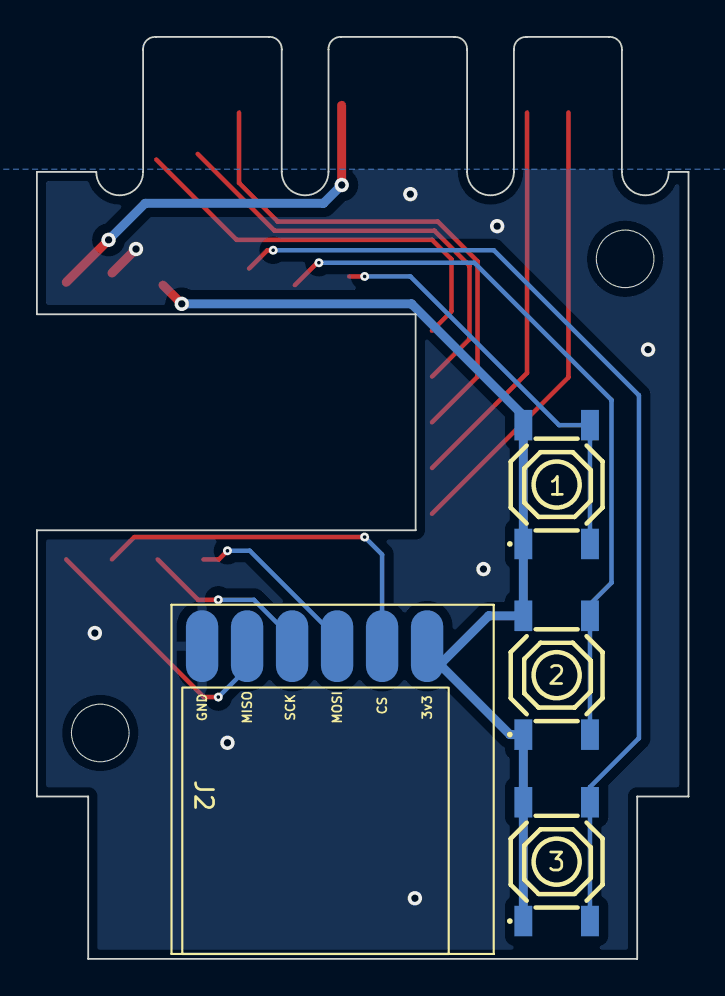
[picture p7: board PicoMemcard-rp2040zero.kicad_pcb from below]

Board: 2 copper layers, 36.2 x 51.2 mm, 8 parts (4 on the bottom side), 15 nets.

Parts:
1, 2, 3: TS-1187A-B-A-B; SW-SMD_4P-L5.1-W5.1-P3.70-LS6.5-TL-2
H1, H2: M3; MountingHole_3.2mm_M3
J1: PSX Memory Card Interface; MemoryCardConnector
J2: MicroSD SPI; MicroSD_SPI_small
U1: rp2040-zero; rp2040-zero-smd

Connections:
+3V3: 1.1 (A), 1.2 (B), 2.1 (A), 2.2 (B), 3.1 (A), 3.2 (B), J2.1, U1.21 (3V3)
+5V: J1.5 (5V), U1.23 (5V)
ACK: J1.8 (ACK), U1.14 (13)
CLK: J1.7 (CLK), U1.13 (12)
CMD: J1.2 (CMD), U1.11 (10)
CS: J2.2, U1.2 (1)
DAT: J1.1 (DAT), U1.10 (9)
GND: J1.4 (GND), J2.6, U1.22 (GND)
GP26: 1.3 (C), 1.4 (D), U1.17 (26)
GP27: 2.3 (C), 2.4 (D), U1.18 (27)
GP28: 3.3 (C), 3.4 (D), U1.19 (28)
MISO: J2.5, U1.1 (0)
MOSI: J2.3, U1.4 (3)
SCK: J2.4, U1.3 (2)
SEL: J1.6 (SEL), U1.12 (11)

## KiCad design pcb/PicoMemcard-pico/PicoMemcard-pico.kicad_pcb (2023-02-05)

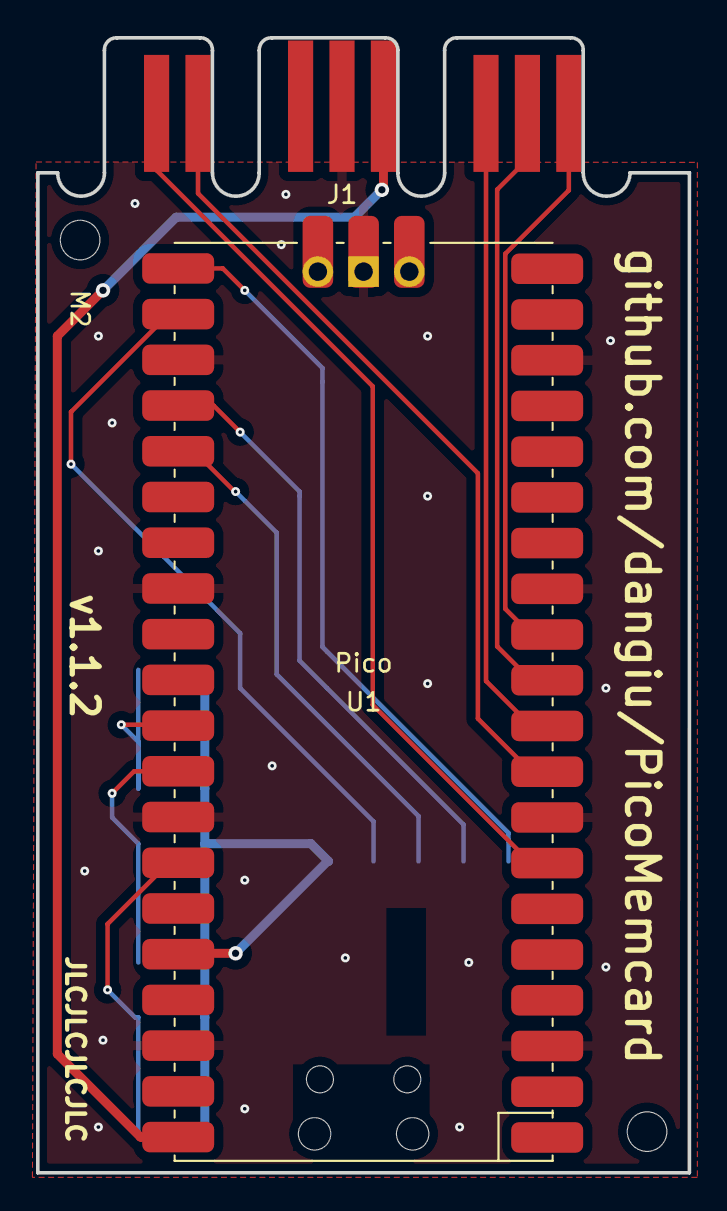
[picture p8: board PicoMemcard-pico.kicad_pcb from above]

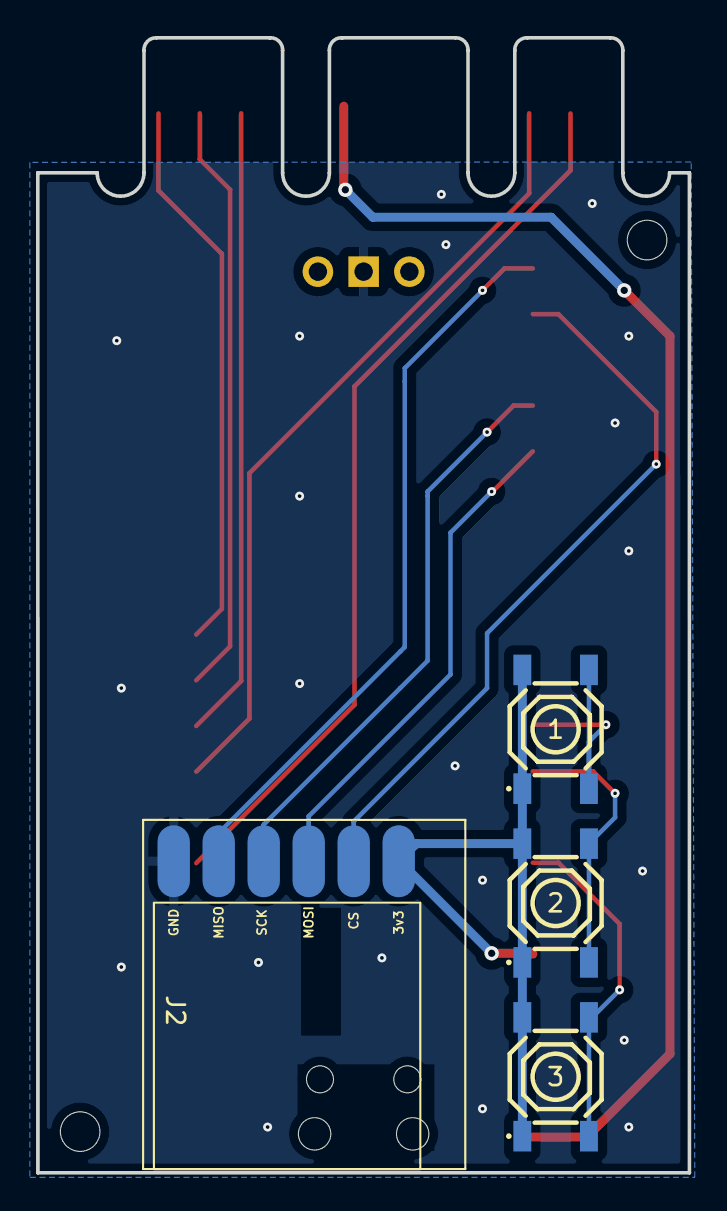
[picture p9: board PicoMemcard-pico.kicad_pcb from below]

Board: 2 copper layers, 36.2 x 63.1 mm, 8 parts (4 on the bottom side), 15 nets.

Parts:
1, 2, 3: TS-1187A-B-A-B; SW-SMD_4P-L5.1-W5.1-P3.70-LS6.5-TL-2
J1: PSX Memory Card Interface; MemoryCardConnector
J2: microSD_SPI_small; MicroSD_SPI_small
M2, M2#2: MountingHole; MountingHole_2.2mm_M2_DIN965
U1: Pico; RPi_Pico_SMD_TH

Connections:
+3V3: 1.1 (A), 1.2 (B), 2.1 (A), 2.2 (B), 3.1 (A), 3.2 (B), J2.1, U1.36 (3V3)
+5V: J1.5 (3.3V), U1.40 (VBUS)
ACK: J1.8 (ACK), U1.12 (GPIO9)
CLK: J1.7 (CLK), U1.11 (GPIO8)
CMD: J1.2 (CMD), U1.9 (GPIO6)
CS: J2.2, U1.22 (GPIO17)
DAT: J1.1 (DAT), U1.7 (GPIO5)
GND: J1.4 (GND), J2.6, U1.3 (GND), U1.8 (GND), U1.13 (GND), U1.18 (GND), U1.23 (GND), U1.28 (GND), U1.33 (AGND), U1.38 (GND), U1.42 (GND)
GP26: 1.3 (C), 1.4 (D), U1.31 (GPIO26_ADC0)
GP27: 2.3 (C), 2.4 (D), U1.32 (GPIO27_ADC1)
GP28: 3.3 (C), 3.4 (D), U1.34 (GPIO28_ADC2)
MISO: J2.5, U1.21 (GPIO16)
MOSI: J2.3, U1.25 (GPIO19)
SCK: J2.4, U1.24 (GPIO18)
SEL: J1.6 (SEL), U1.10 (GPIO7)

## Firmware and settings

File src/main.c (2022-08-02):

#include "pico/stdio.h"
#include "pico/stdlib.h"
/* SD Card */
#include "sd_config.h"
/* Time and Timestamps */
#include "pico/time.h"
/* TinyUSB */
#include "bsp/board.h"
#include "tusb.h"
/* Memcard Simulation */
#include "memcard_simulator.h"
/* LED Control */
#include "led.h"
/* Global Configuration */
#include "config.h"


bool tud_mount_status = false;

void cdc_task(void);

/*------------- MAIN -------------*/
int main(void) {
	stdio_init_all();
	led_init();
	
	/* Pico connected to PC, initialize USB transfer mode */
	board_init();
	tusb_init();

	while(true) {
		tud_task(); // tinyusb device task
		cdc_task();

		if(to_ms_since_boot(get_absolute_time()) > TUD_MOUNT_TIMEOUT && !tud_mount_status)
			break;
	}
	
	/* Pico powered by PSX, initialize memory card simulation */
	simulate_memory_card();	

	return 0;
}

//--------------------------------------------------------------------+
// Device callbacks
//--------------------------------------------------------------------+

// Invoked when device is mounted
void tud_mount_cb(void) {
	tud_mount_status = true;
	/* Initialize SD card */
	sd_card_t *p_sd = sd_get_by_num(0);
	if (!p_sd) return;
	sd_init_card(p_sd);
}

// Invoked when device is unmounted
void tud_umount_cb(void) {}

// Invoked when usb bus is suspended
// remote_wakeup_en : if host allow us  to perform remote wakeup
// Within 7ms, device must draw an average of current less than 2.5 mA from bus
void tud_suspend_cb(bool remote_wakeup_en) {
	(void) remote_wakeup_en;
}

// Invoked when usb bus is resumed
void tud_resume_cb(void) {}

//--------------------------------------------------------------------+
// USB CDC
//--------------------------------------------------------------------+
void cdc_task(void) {
	// connected() check for DTR bit
	// Most but not all terminal client set this when making connection
	// if ( tud_cdc_connected() )
	{
		// connected and there are data available
		if ( tud_cdc_available() )
		{
			// read datas
			char buf[64];
			uint32_t count = tud_cdc_read(buf, sizeof(buf));
			(void) count;

			// Echo back
			// Note: Skip echo by commenting out write() and write_flush()
			// for throughput test e.g
			//    $ dd if=/dev/zero of=/dev/ttyACM0 count=10000
			tud_cdc_write(buf, count);
			tud_cdc_write_flush();
		}
	}
}

// Invoked when cdc when line state changed e.g connected/disconnected
void tud_cdc_line_state_cb(uint8_t itf, bool dtr, bool rts) {
	(void) itf;
	(void) rts;
}

// Invoked when CDC interface received data from host
void tud_cdc_rx_cb(uint8_t itf) {
	(void) itf;
}

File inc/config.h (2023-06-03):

#ifndef __CONFIG_H__
#define __CONFIG_H__

/* Global configuration options for PicoMemcard */
#define TUD_MOUNT_TIMEOUT	3000			// max time (in ms) before giving up on MSC mode (USB) and starting memcard simulation
#define MSC_WRITE_SYNC_TIMEOUT 1 * 1000		// time (in ms) expired since last MSC write before exporting RAM disk into LFS
#define IDLE_AUTOSYNC_TIMEOUT 5 * 1000		// time (in ms) the memory card must be inactive before automatic sync from RAM to LFS
#define MAX_MC_FILENAME_LEN	32				// max length of memory card file name (including extension)
#define MAX_MC_IMAGES	255					// maximum number of different mc images
#define MC_RECONNECT_TIME	1000				// time (in ms) the memory card stays disconnected when simulating reconnection

/* Board targeted by build */
#define PICO
//#define RP2040ZERO

/* Invert red and green. Uncomment this if the LED colours for your RP2040 Zero are incorrect. */
#define INVERT_RED_GREEN

/* PSX Interface Pinout */
#ifdef PICO                 // TODO remove/find way to include this into pio code
	//#define PIN_DAT 5
	//#define PIN_CMD PIN_DAT + 1		// must be immediately after PIN_DAT
	//#define PIN_SEL PIN_CMD + 1		// must be immediately after PIN_CMD
	//#define PIN_CLK PIN_SEL + 1		// must be immediately after PIN_SEL
	//#define PIN_ACK 9
#endif

#ifdef RP2040ZERO           // TODO remove/find way to include this into pio code
	#define PIN_DAT 9
	#define PIN_CMD PIN_DAT + 1		// must be immediately after PIN_DAT
	#define PIN_SEL PIN_CMD + 1		// must be immediately after PIN_CMD
	#define PIN_CLK PIN_SEL + 1		// must be immediately after PIN_SEL
	#define PIN_ACK 13
#endif

/* SD Card Configuration */
#define BLOCK_SIZE	512				// SD card communicate using only 512 block size for consistency
#define BAUD_RATE	5000 * 1000
#ifdef PICO
	#define PIN_MISO	16
	#define PIN_MOSI	19
	#define PIN_SCK		18
	#define PIN_SS		17
#endif

#ifdef RP2040ZERO
	#define PIN_MISO	0
	#define PIN_MOSI	3
	#define PIN_SCK		2
	#define PIN_SS		1
#endif

#endif

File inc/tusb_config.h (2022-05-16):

/*
 * The MIT License (MIT)
 *
 * Copyright (c) 2019 Ha Thach (tinyusb.org)
 *
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
 */

#ifndef _TUSB_CONFIG_H_
#define _TUSB_CONFIG_H_

#ifdef __cplusplus
 extern "C" {
#endif

//--------------------------------------------------------------------
// COMMON CONFIGURATION
//--------------------------------------------------------------------

// defined by board.mk
#ifndef CFG_TUSB_MCU
  #error CFG_TUSB_MCU must be defined
#endif

// RHPort number used for device can be defined by board.mk, default to port 0
#ifndef BOARD_DEVICE_RHPORT_NUM
  #define BOARD_DEVICE_RHPORT_NUM     0
#endif

// RHPort max operational speed can defined by board.mk
// Default to max (auto) speed for MCU with internal HighSpeed PHY
#ifndef BOARD_DEVICE_RHPORT_SPEED
  #define BOARD_DEVICE_RHPORT_SPEED   OPT_MODE_FULL_SPEED
#endif

// Device mode with rhport and speed defined by board.mk
#if   BOARD_DEVICE_RHPORT_NUM == 0
  #define CFG_TUSB_RHPORT0_MODE     (OPT_MODE_DEVICE | BOARD_DEVICE_RHPORT_SPEED)
#elif BOARD_DEVICE_RHPORT_NUM == 1
  #define CFG_TUSB_RHPORT1_MODE     (OPT_MODE_DEVICE | BOARD_DEVICE_RHPORT_SPEED)
#else
  #error "Incorrect RHPort configuration"
#endif

// This example doesn't use an RTOS
#ifndef CFG_TUSB_OS
#define CFG_TUSB_OS               OPT_OS_NONE
#endif

// CFG_TUSB_DEBUG is defined by compiler in DEBUG build
// #define CFG_TUSB_DEBUG           0

/* USB DMA on some MCUs can only access a specific SRAM region with restriction on alignment.
 * Tinyusb use follows macros to declare transferring memory so that they can be put
 * into those specific section.
 * e.g
 * - CFG_TUSB_MEM SECTION : __attribute__ (( section(".usb_ram") ))
 * - CFG_TUSB_MEM_ALIGN   : __attribute__ ((aligned(4)))
 */
#ifndef CFG_TUSB_MEM_SECTION
#define CFG_TUSB_MEM_SECTION
#endif

#ifndef CFG_TUSB_MEM_ALIGN
#define CFG_TUSB_MEM_ALIGN          __attribute__ ((aligned(4)))
#endif

//--------------------------------------------------------------------
// DEVICE CONFIGURATION
//--------------------------------------------------------------------

#ifndef CFG_TUD_ENDPOINT0_SIZE
#define CFG_TUD_ENDPOINT0_SIZE    64
#endif

//------------- CLASS -------------//
#define CFG_TUD_CDC              1
#define CFG_TUD_MSC              1
#define CFG_TUD_HID              0
#define CFG_TUD_MIDI             0
#define CFG_TUD_VENDOR           0

// CDC FIFO size of TX and RX
#define CFG_TUD_CDC_RX_BUFSIZE   (TUD_OPT_HIGH_SPEED ? 512 : 64)
#define CFG_TUD_CDC_TX_BUFSIZE   (TUD_OPT_HIGH_SPEED ? 512 : 64)

// CDC Endpoint transfer buffer size, more is faster
#define CFG_TUD_CDC_EP_BUFSIZE   (TUD_OPT_HIGH_SPEED ? 512 : 64)

// MSC Buffer size of Device Mass storage
#define CFG_TUD_MSC_EP_BUFSIZE   512

#ifdef __cplusplus
 }
#endif

#endif /* _TUSB_CONFIG_H_ */

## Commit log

2022-04-05 Initial testing of custom SPI, able to read correctly CMD, unable to answer using DAT and ACK
2022-04-08 Update IDE configuration, add PIO sm supporting modified psx spi, add showcase of joypad toggle
2022-05-14 Update CMake and launch configuration, add led status indicator to memcard simulation mode
2022-05-23 Enlarge virtual FAT disk to accomodate Windows Storage Service data preventing user from transfering memory card image on first installation
    [main.c]
2022-06-05 Update README.md, add Custom PCB section
2022-06-10 Added SD card mount error check.
    [main.c]
2022-07-10 Add sector log and fix issue where the syncing process was treating the sector number as an absolute address.
    [memcard_simulator.c]
2022-08-01 Code refractoring & reimplementation of USB functionality - reworked memory_card (initialization, null check, error codes, type and more) - reintroduced MSC capabilities (previosly removed) - reduced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
    [config.h, led.c, main.c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]
2022-08-01 Reworked queue sync: cleaner faster and less memory used, add sync status led
    [config.h, memcard_simulator.c]
2022-08-02 Add multiple memory card image support, with controller input for switching
2022-08-02 Add SD pinout to global configuration, fix RP2040-Zero SD pinouts
    [config.h, sd_config.c]
2022-08-25 Rework image switching to lookup explicitely filesystem instead of using blind index, fixes #16
    [config.h, led.c, memcard_manager.h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]
2022-08-26 Add controller input (STRT+SEL+TRNGL) to create new empty memory card image and switch to it, closes #21
2022-08-31 Fix WS2812 LED passing data on DO instead of interpreting it, update color scheme
    [led.c]
2023-02-03 PicoMemCard+ now reloads the last card you had loaded after a restart.
    Handles creating new cards, index being out of range and the dat file not existing.
    Changed out of sync state LED to red, as orange looks very similar to green on RP2040 Zero.
    Added small delay to out of sync state LED as previously it would flash green and red/orange quickly and would be hard to see if it is still syncing. Note: This doesn't add any noticeable delay to saving.
    Added flag to invert red and green for newer RP2040 Zero boards.
    [config.h, led.c, memcard_manager.h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]
2023-02-05 Update README, add KiCad and Gerber for new PCB
    [PicoMemcard-pico-B_Cu.gbr, PicoMemcard-pico-B_Mask.gbr, PicoMemcard-pico-B_Paste.gbr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]
2023-03-19 PICO_DEFAULT_LED_PIN is already defined in pico.h
2023-03-19 Pico_W LED Support
2023-03-19 Fixed bug caused by find/replace
    [led.c]
2023-05-12 Add improved PIO code, add improved interrupt and ack handling, general code cleanup
2023-05-12 Refractor code, improved queue and transition handling, switch from sm approach to linear one
2023-06-03 Fix pio code, improve output
    [memcard_simulator.c]
2023-06-03 Fix bad function definition when compiling for RP2040-Zero
    [led.c]
